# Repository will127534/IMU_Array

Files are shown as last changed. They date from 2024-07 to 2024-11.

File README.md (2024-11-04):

# IMU sensor Array   
Based on 32x ICM-42688-P and ICE40UP5K

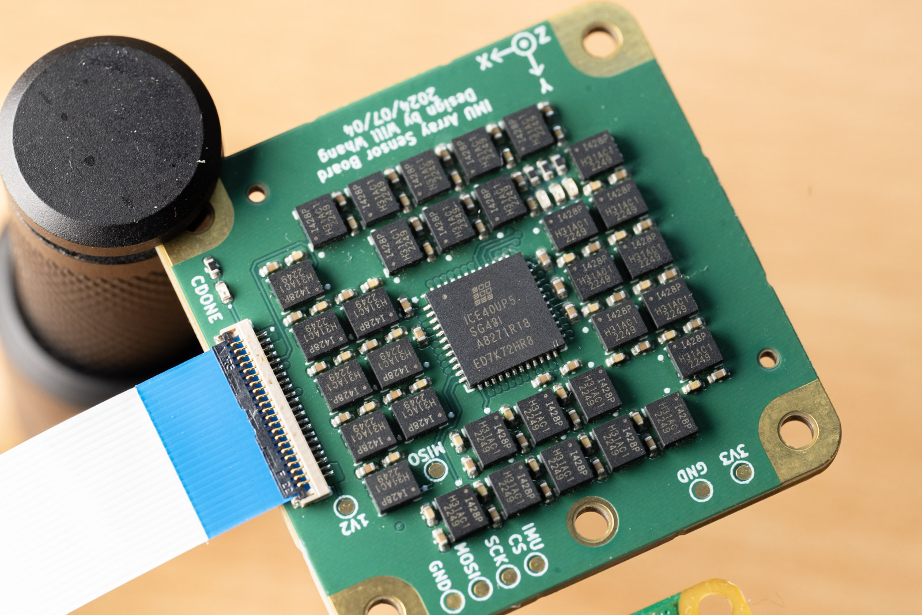
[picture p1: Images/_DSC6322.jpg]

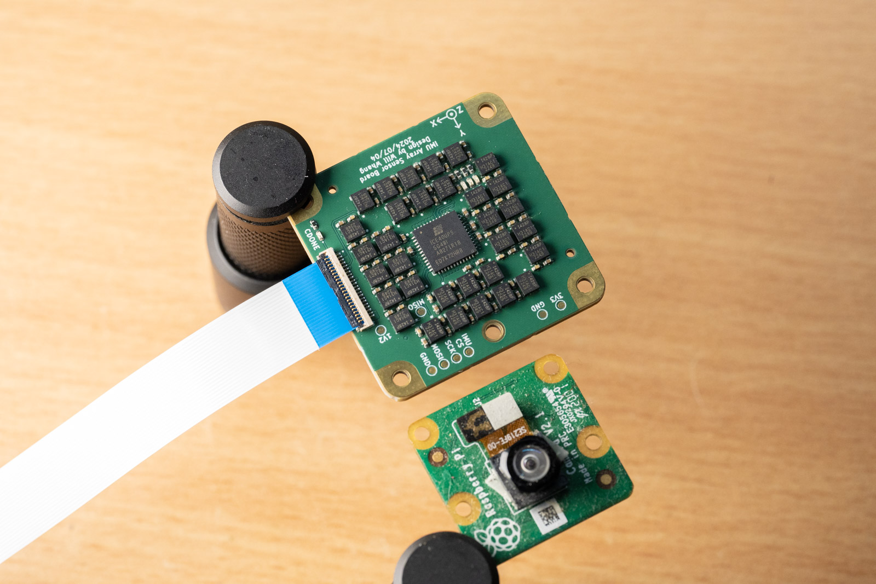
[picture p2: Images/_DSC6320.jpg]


## System Block Diagram
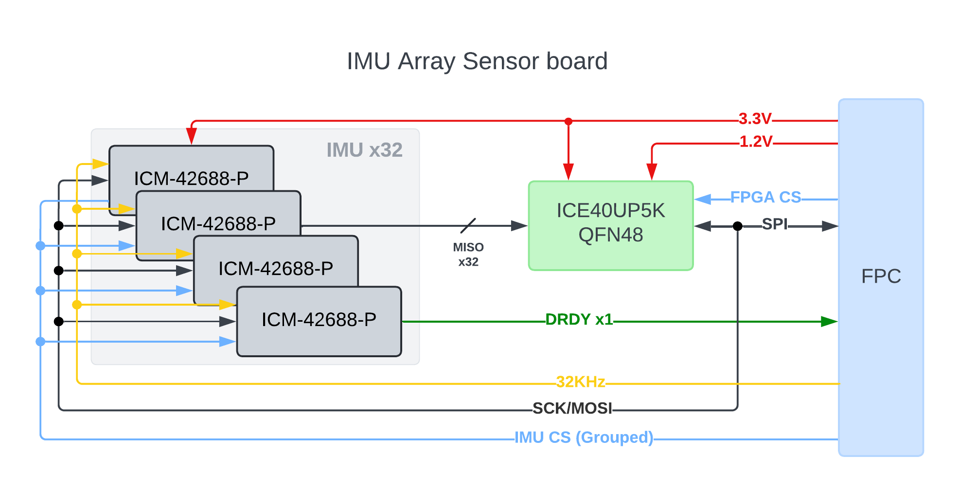
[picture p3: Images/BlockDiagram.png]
BlockDiagram


Blog post: [https://www.willwhang.dev/Project-IMU-Array/](https://www.willwhang.dev/Project-IMU-Array/)

## Dictionary Structure

* IMUArray_SensorBoard: KiCad files for the Sensor board
* IMUArray_BreakoutBoard: KiCad files for the Sensor breakout board with Raspberry Pi Pico  
* MicroPythonCode: MicroPython code for Raspberry Pi Pico  
* FPGACode: Verilog files for the FPGA

## Notes
The hardware is specifically designed for 6-layer board and as you can see from the photos it is using via-in-pad, though I still need to use smaller via dimensions (0.2mm drill). Gerber, BOM and CPL files are also available. Or you can order it from PCBWay [here](https://www.pcbway.com/project/shareproject/IMU_Array_Sensor_board_84cfc54a.html). (Thank you PCBWay for sponsering this project!)

You can have them populate top side only, the back side are some 0402 decoupling caps that can be easily hand soldered. Do note that the FPC connector is selected because it has the least width, but the plastic latch is way fragile then I though, so becareful.   

As for the breakout board, it is really just for supporting the bring up process, I'm gonna design some other based boards to use this IMU array for my other projects (Geophone replacements).  

The code is still in its early stages so there isn't a lot of "Handy" functions to set different ODR (Sampling rate)/FSR (Full Scale range) and functions, but mostly just hand calculated values for the registers. Rightnow it is set to 200Hz sampling rate with interupt and external 32Khz clock enabled. For the Verilog code, please don't judge, I'm too lazy to save 4096 LUTs for the 512 byte IMU data, I mean for some reason ICE40UP5K is pretty cheap so I might as will to utilized it fully, right?  

Most importantly, the code right now does not do any fancy data processing but only reading out 32x IMU data and either send all of them or do a simple average (accumulating only actually) and output the result (it does handle the 4 different rotations of the IMUs).  

The project is still in developments, and here are the issues:  
1. SPI clock is not stable higher then 5Mhz to the FPGA, work is on-going to move the data shifting posedge from ICE40 internal 48Mhz clock to use SCK directly.  
    UPDATE on 2024/08/04 - This has been resolved, now I can run the SPI at 20Mhz.
2. Currently it is not possible to send out all IMU data at 200Hz, but only the averaged value. The bottleneck is in microPython code to print out the data to USB-CDC.  
   UPDATE on 2024/08/04 - Overclocked to 250Mhz so I can send out 100Hz x32 IMUs data to PC, so the focus now is the algorithm to filter out data.

## Footnotes

ICE40 micropython/circuitpython upload code from:   
https://github.com/skerr92/Oakdevtech_CircuitPython_IcePython  
Which is actually designed for the IcyBlue FPGA Feather board (ICE40 + RP2040 on a Feather board)   
https://www.tindie.com/products/oakdevtech/icyblue-fpga-feather-v2/  

[Interactive BOM](https://htmlpreview.github.io/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) [(provided by InteractiveHtmlBom)
](https://github.com/openscopeproject/InteractiveHtmlBom) 

Papers and Inspirations:  
1. The inspirations comes from Sony's crazy 16x IMU array board for SPRESENSE, which is so powerfull that is it export controlled.   

https://monoist.itmedia.co.jp/mn/articles/2404/26/news134.html

2. Kamata, Hiroyuki et al. “MEMS Gyro Array Employing Array Signal Processing for Interference and Outlier Suppression.” 2020 IEEE International Symposium on Inertial Sensors and Systems (INERTIAL) (2020): 1-4. 
https://ieeexplore.ieee.org/document/9090089   
https://www.kenkai.jaxa.jp/research/innovation/multi_imu.html  
https://www.sony.com/ja/SonyInfo/technology/stories/entries/Spresense/  
This is also what Sony's IMU array board is based of I think.

3. Blocher, Lukas et al. “Purely Inertial Navigation with a Low-Cost MEMS Sensor Array.” 2021 IEEE International Symposium on Inertial Sensors and Systems (INERTIAL) (2021): 1-4.
https://ieeexplore.ieee.org/document/9430468

5. Wang, Liqiang et al. “Improving the Navigation Performance of the MEMS IMU Array by Precise Calibration.” IEEE Sensors Journal 21 (2021): 26050-26058.
http://i2nav.com/ueditor/jsp/upload/file/20221125/1669361019644065348.pdf

6. Nilsson, John-Olof et al. “Aligning the Forces—Eliminating the Misalignments in IMU Arrays.” IEEE Transactions on Instrumentation and Measurement 63 (2014): 2498-2500.
https://ieeexplore.ieee.org/document/6879287

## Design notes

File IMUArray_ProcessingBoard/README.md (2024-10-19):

# IMU Array Data Processing Board

Here is the board and code for the processing board I'm designing mainly for my geophone replacement project.
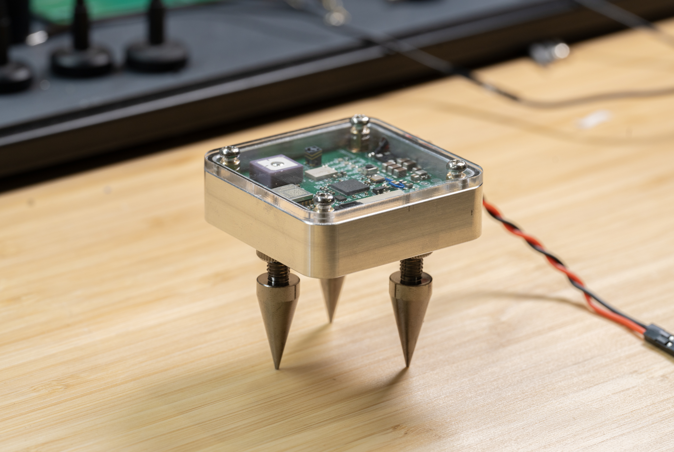
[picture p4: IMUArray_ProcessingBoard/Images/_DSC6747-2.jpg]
Board photo


## System Block Diagram
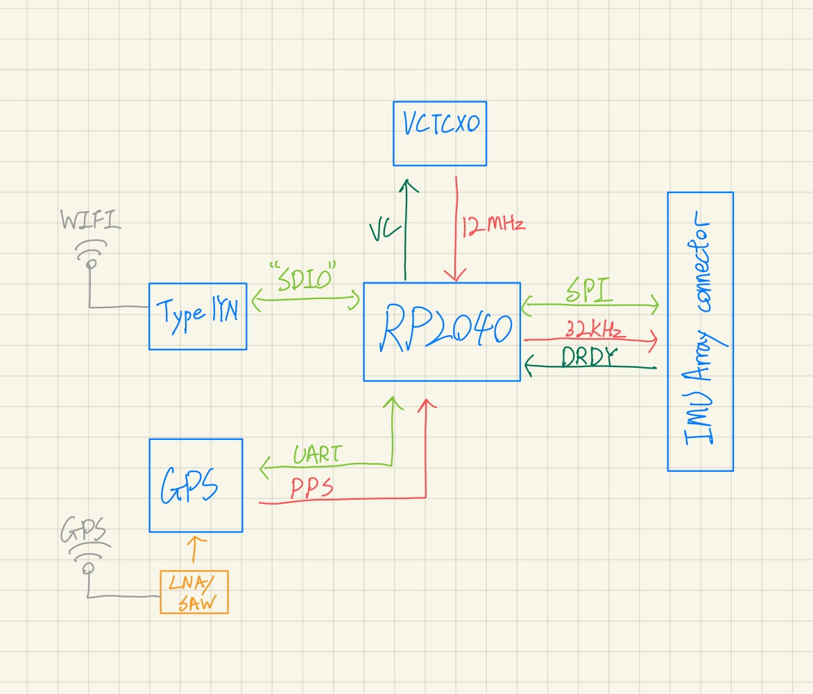
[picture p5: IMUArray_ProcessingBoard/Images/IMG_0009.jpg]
System Block Diagram


## Dictionary Structure

* IMUArray_ProcessingBoard: KiCad files for the board
* Code: C Code for the board

## Hardware Notes

So, long story short, this is essentially a custom-built Pico W using the same RP2040 + CYW43439 (Type 1YN) combo. Additionally, the crystal for the RP2040 was replaced with a VCTCXO, allowing me to tune the onboard clock to match the GPS clock (i.e., GPSDO). The code supports both NTP and GPS+PPS as time sync sources. The main reason for this is that I’m using the same crystal to send a stable 32kHz signal to the IMU array.

You might ask, why on earth do I have a full bridge rectifier along with a high-voltage DC-DC step-down converter? This was mainly because I initially intended to use my doorbell system (24V AC) to power the system. I kind of regret this decision, so it was removed in v2.0 (I’m waiting for the board to arrive).

Furthermore, I originally planned to rely on Wi-Fi to transmit the data, so the USB connector (JST-SH) wasn’t designed for external connection but only for programming. See more on the blog post. However, I ended up deciding to make the USB accessible from the case in the future v2.0 design.

## Software Notes

In the code folder, you’ll find two files. The goal for `imu_simple` is to have a much simpler codebase, so two years later, I can still understand what’s going on or easily test new ideas. `imu_main` is the main code I’m currently using, which follows the structure outlined below:

The data can be sent via either TCP or USB. If a client connects to the TCP server, it will switch to sending data through TCP. During startup, and once per hour, the system performs an NTP time sync. If GPS is available, it also uses it to calculate the UNIX timestamp offset from the internal system clock. As a result, each IMU sample contains not only the timestamp from the IMU itself but also a UNIX timestamp. However, note that these two timestamps are not strongly related (since the GPSDO requires time to adjust the error).

For IMU data processing, the code uses the method described in Reference 6 to calibrate the IMU array. Refer to the MATLAB code section for generating imu_cal.h. The data processing applies the calibration and merges the 32 IMU data into one dataset. The RP2040 is surprisingly fast enough to handle all of this using floating-point operations, even without hardware FPU, and can run at up to 500Hz. A side note here is that to measure the processing time, I placed the data processing code along with the SPI read function. By measuring the CS pin, I can determine the total time spent on both data acquisition and processing. The 500Hz rate accounts for both tasks in sequence, not in parallel (i.e., I’m not using both CPU cores for reading and processing, but instead for reading/processing and Wi-Fi/Bluetooth data processing).

Lastly, I’m not entirely sure how to share the code I wrote under the RP2040 SDK’s pico-example folder, so you may need to figure out how to set up the build environment outside of the SDK. Also, please let me know how to share it if you have suggestions.

## Footnotes

[Interactive BOM](https://htmlpreview.github.io/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) [(provided by InteractiveHtmlBom)
](https://github.com/openscopeproject/InteractiveHtmlBom) 

PIO input capture code from: https://people.ece.cornell.edu/land/courses/ece4760/RP2040/C_SDK_PIO_control/Input_capture/index_pio_control.html

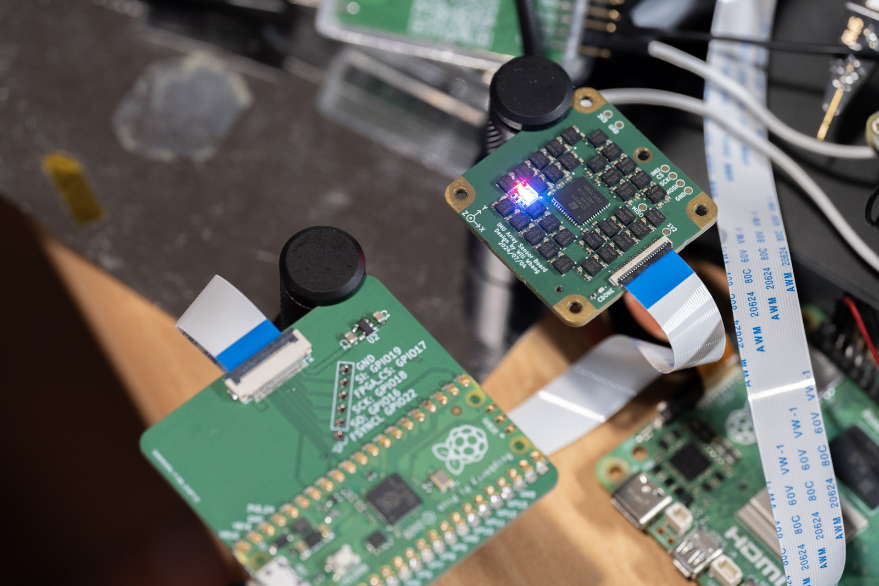
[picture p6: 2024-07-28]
Images/_DSC6333.jpg

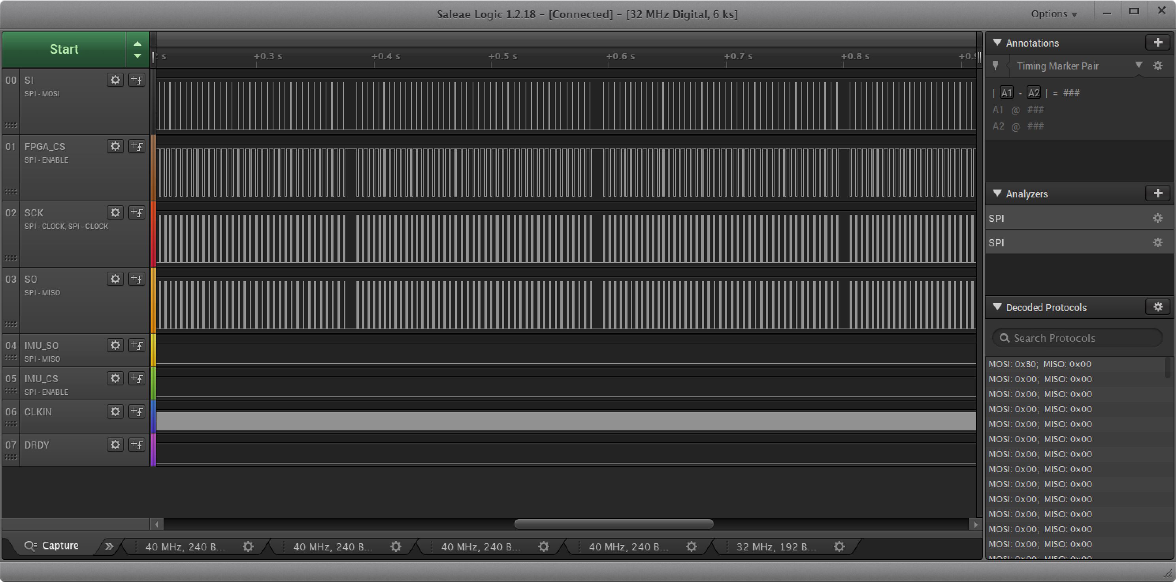
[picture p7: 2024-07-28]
Images/WaveForm1.jpg

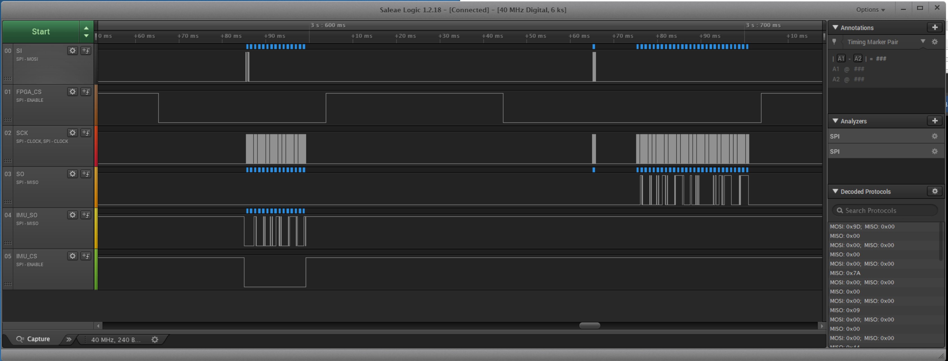
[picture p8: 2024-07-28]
Images/WaveForm2.jpg

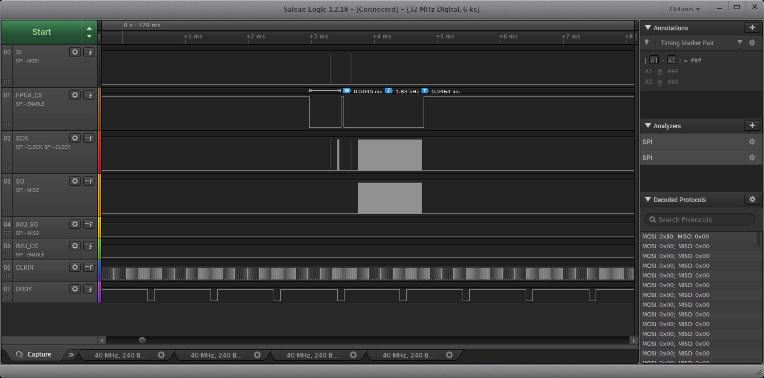
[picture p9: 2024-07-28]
Images/WaveForm3.jpg

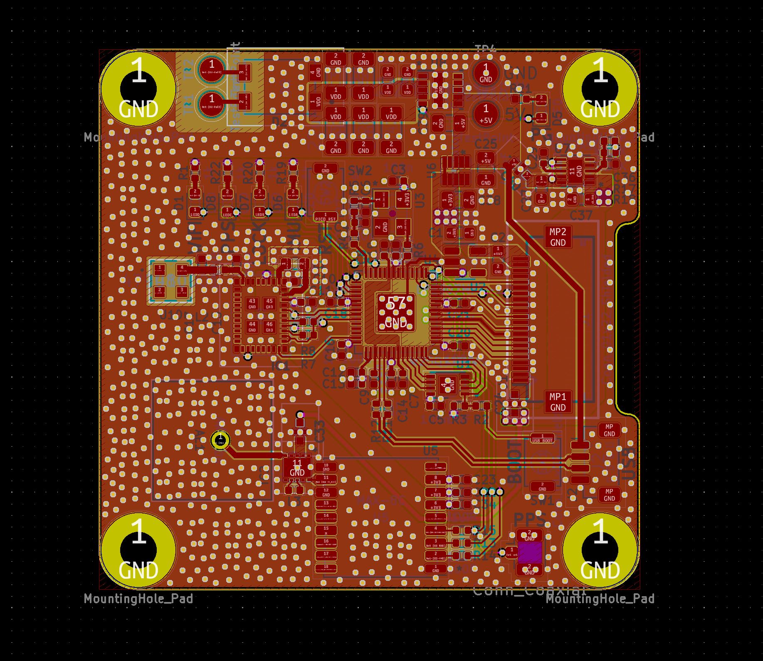
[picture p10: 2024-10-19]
IMUArray_ProcessingBoard/IMUArray_ProcessingBoard/board.jpg

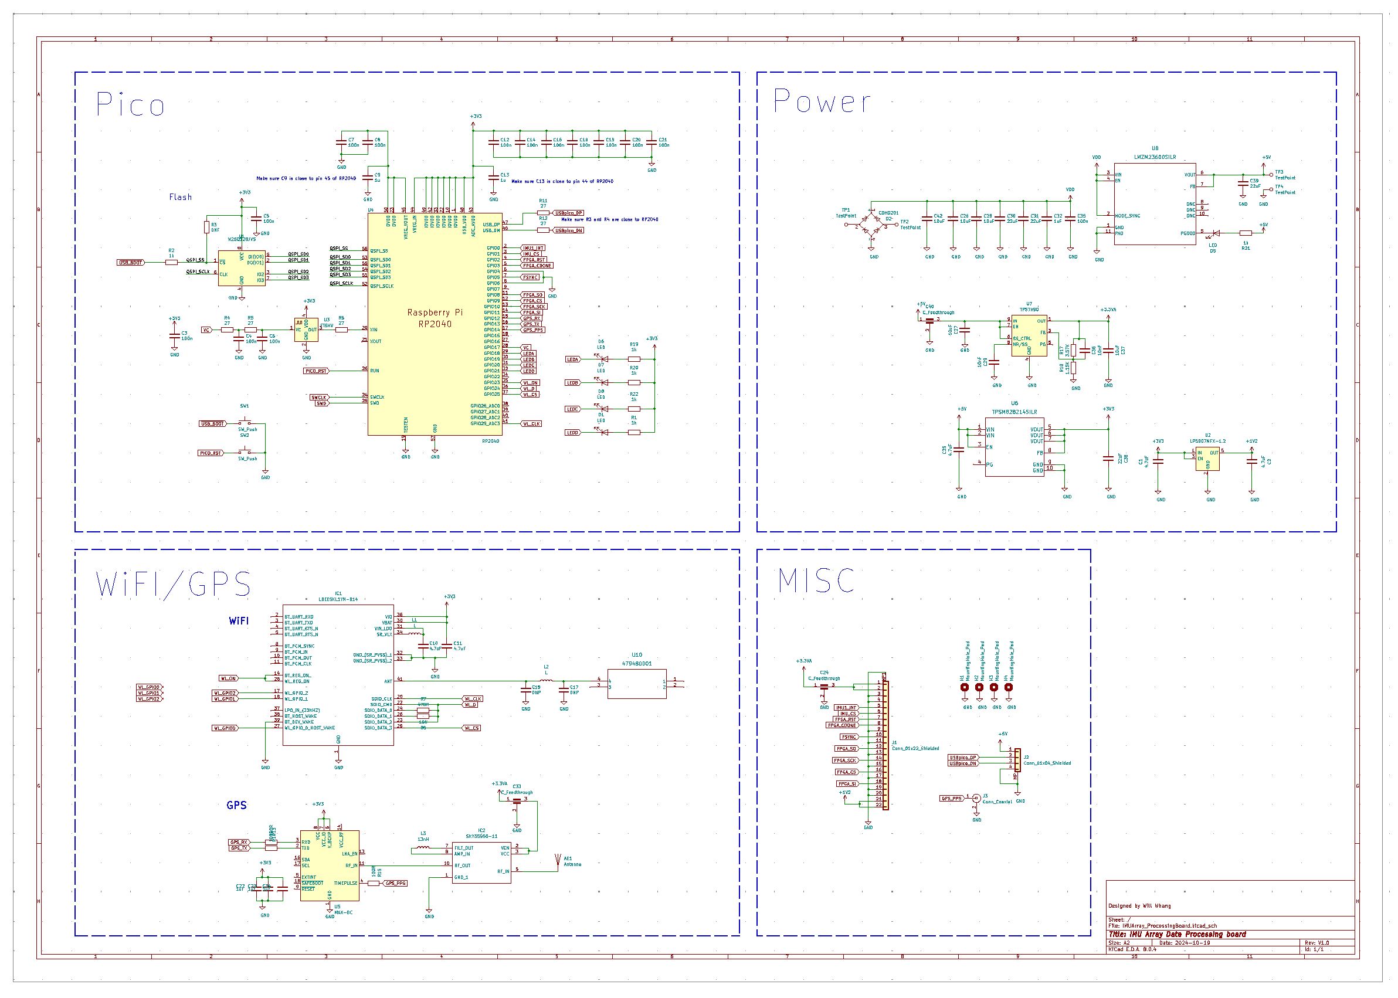
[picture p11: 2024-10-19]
IMUArray_ProcessingBoard/IMUArray_ProcessingBoard/sch.jpg

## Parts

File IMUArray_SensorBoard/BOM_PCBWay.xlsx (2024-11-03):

 |  |  | IMU array Sensor 1PCS BOM (Sample Bill of Materials)
Item # | *Designator | *Qty | Manufacturer | *Mfg Part # | Description / Value | *Package/Footprint | Type | Your Instructions / Notes
1 | C1, C2, C4, C5, C6, C7, C8, C9, C10, C11, C12, C13, C14, C15, C32, C33, C34, C35, C36, C37, C38, C39, C56, C57, C58, C59, C60, C61, C62, C63, C80, C81, C82, C83, C84, C85, C86, C87, C111 | 39 |  |  | CAP CER 100nF 16V X7R 0402 | 0402 | SMD
2 | C16, C17, C18, C19, C20, C21, C22, C23, C40, C41, C42, C43, C44, C45, C46, C47, C64, C65, C66, C67, C68, C69, C70, C71, C88, C89, C90, C91, C92, C93, C94, C95 | 32 |  |  | CAP CER 10nF 16V X7R 0402 | 0402 | SMD
3 | R3, R4, R5, R6 | 4 |  |  | RES 330R OHM 1/8W 1% 0402 SMD | 0402 | SMD
4 | D1, D3 | 2 |  |  | GREEN LED 0402 | 0402 | SMD
5 | D2 | 1 |  |  | RED LED 0402 | 0402 | SMD
6 | D4 | 1 |  |  | BLUE LED 0402 | 0402 | SMD
7 | U1, U2, U3, U4, U5, U6, U7, U8, U9, U10, U11, U12, U13, U14, U15, U16, U17, U18, U19, U20, U21, U22, U23, U24, U25, U26, U27, U28, U29, U30, U31, U32 | 32 | TDK InvenSense | ICM-42688-P | ICM42688-P IMU | PQFN50P300X250X97-14N | SMD
8 | U33 | 1 | Lattice | ICE5LP1K-SG48 | ICE5LP1K-SG48 | QFN-48 | SMD
9 | J1 | 1 | Hirose | FH19SC22S05SH09 | FH19SC22S05SH09 | Conn_01x22_Shielded | SMD
Need a quick and accurante quote? Need an efficient production? Please read SMT Ordering Necessary Files & Info in 1 minute. Thank you very much! (https://www.pcbway.com/smt_ordering_guide.html)
Click for Instructions on How to Create a BOM (https://www.pcbway.com/blog/PCB_Assembly/How_to_Build_a_BOM__Bill_Of_Materials_.html)

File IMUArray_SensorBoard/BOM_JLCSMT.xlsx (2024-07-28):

Comment | Designator | Footprint | JLCPCB Part #（optional）
330R | R3,R6,R5,R4 | R_0402_1005Metric | C245037
10nF | C21,C67,C40,C69,C44,C94,C65,C47,C19,C64,C18,C66,C92,C88,C91,C95,C17,C42,C16,C93,C20,C71,C68,C43,C70,C23,C45,C46,C90,C89,C22,C41 | C_0402_1005Metric | C338031
100n | C87,C86,C85,C63,C62,C61,C39,C38,C15,C14,C13,C12,C11,C35,C37,C36,C84,C34,C8,C80,C33,C60,C58,C6,C59,C57,C32,C56,C82,C4,C81,C83,C5,C1,C2,C7,C111,C9,C10 | C_0402_1005Metric | C3901090
2.2uF | C79,C78,C77,C55,C54,C53,C52,C51,C31,C30,C29,C28,C27,C103,C102,C101,C75,C26,C97,C96,C72,C48,C50,C100,C49,C99,C24,C76,C73,C98,C25,C74 | C_0402_1005Metric
GREEN | D1,D3 | LED_0402_1005Metric | C434449
4.7uF | C3,C113,C112 | C_0402_1005Metric
ICE5LP1K-SG48 | U33 | QFN-48-1EP_7x7mm_P0.5mm_EP5.6x5.6mm | C2678152
ICM-42688-P | U15,U31,U32,U22,U28,U26,U1,U11,U8,U25,U16,U4,U5,U30,U13,U14,U12,U21,U9,U7,U10,U27,U6,U3,U19,U18,U29,U24,U20,U17,U23,U2 | PQFN50P300X250X97-14N | C1850418
BLUE | D4 | LED_0402_1005Metric | C434447
RED | D2 | LED_0402_1005Metric | C434445
Conn_01x22_Shielded | J1 | FH19SC22S05SH09 | C3168185

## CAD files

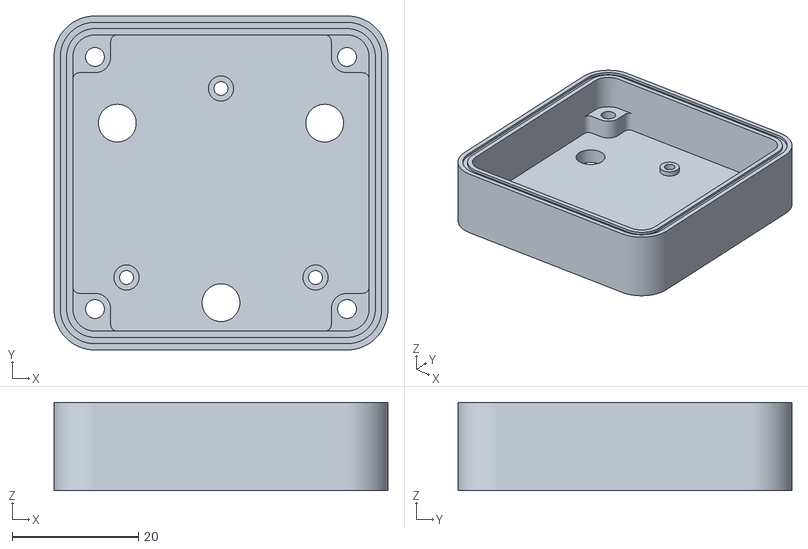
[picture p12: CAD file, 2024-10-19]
IMUArray_ProcessingBoard/3D_STL/Body.stl
53.0 x 53.0 x 14.0

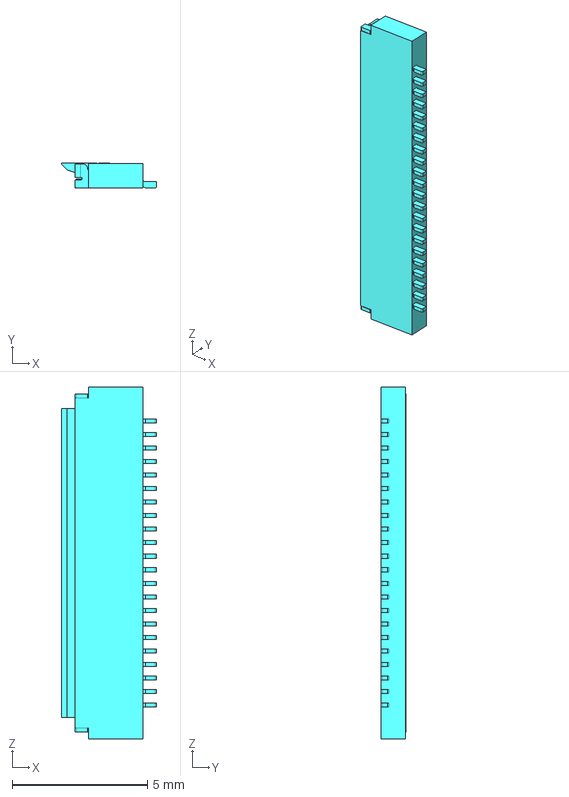
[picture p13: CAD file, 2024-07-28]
IMUArray_SensorBoard/3D/FH19SC-22S-0.5SH(09).STEP
3.50 x 0.93 x 13.0 mm

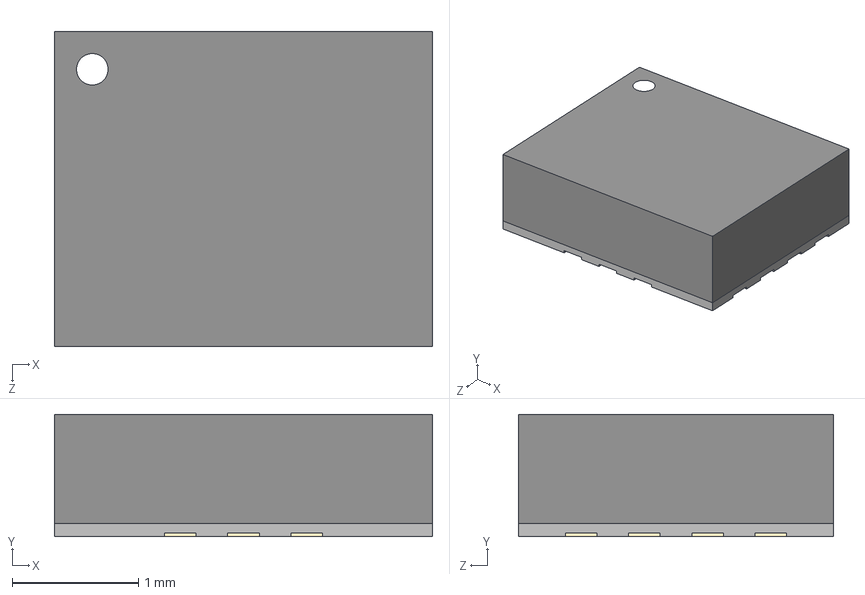
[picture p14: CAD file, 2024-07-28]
IMUArray_SensorBoard/3D/ICM-42688-P.step
3.00 x 0.97 x 2.50 mm

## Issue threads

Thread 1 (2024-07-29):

Is there a dataset demo?

qpc001, 2024-07-29:

will127534, 2024-07-29:
Two separate runs:
[20240728190930.csv](https://github.com/user-attachments/files/16406410/20240728190930.csv)
[20240728190439.csv](https://github.com/user-attachments/files/16406411/20240728190439.csv)

The averaged one is at 200Hz, full data in 50Hz

will127534, 2024-07-29:
full data in 50Hz - I forgot to print it as float. the data is in mg and dps for this.
[20240728191400.csv](https://github.com/user-attachments/files/16406472/20240728191400.csv)

The averaged one is accumulated all the IMUs data in raw ADC.

will127534, 2024-08-02:
Here are the dataset and the code I used to record + analyze.
https://github.com/will127534/IMU_Array/tree/analyzer

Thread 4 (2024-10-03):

Avoiding FPGA - possible simplification

aaronjauf, 2024-10-03:
Hello,
very nice project and thank you for sharing!
Did you already try indoor navigation using the IMU array and are do you expect 100 Hz to be enough for a e.g. vacuum cleaner rover?
I was wondering if the FPGA can be eliminated: My idea is to use a raspberry pi pico and interfacing the I2C interfaces of the IMUs using the PIO/DMA. The clock line can be shared, allowing for 27 IMUs (since the pico has 28 gpio lines), if all IMUs are set to the same I2C address, otherwise 54 IMUs. What's your opinion on this?

Best regards
Aaron

will127534, 2024-10-04:
So originally I did think about using RP2040 but because of the lack of GPIO (I want to do 32 IMU) and some bad timing (RP2350 released a couple weeks after I got the board back), I end up going with a FPGA, but it is not that expensive though.

Issue with I2C is speed and complexity compare to SPI bus, you are limited to 1Mhz while SPI in this project is running at 20Mhz.

Overall if I have a second revision in the future I'll go with RP2350 + SPI to the IMUs, I think that is the ultimate solution.

nippoo, 2024-10-15:
Hey, thanks for the great project! I'm interested in porting this to an MCU - do you have any other thoughts? (I'd happily send over a PR, though likely makes sense to keep two separate projects as it's a bit of a redesign...) I'd like to run some slightly more advanced algorithms: interference suppression (to remove resonances from closely mounted IMUs), an outlier filter (to discard any out-of-tolerance IMUs), and a Kalman filter for position estimation (as well as something to calculate and cancel out the earth's precession!). So I'm considering either the RP2350, or something a little bit more powerful where the SPI I/O can run on one core and the more sophisticated algorithms can run on a fixed 100Hz loop on the other core...

As an aside: why did you choose the ICM-42688-P? It has the same stated random walk (2.8mdps/sqrt(Hz)) as the ST LSM6DSV IMU, which is half the price, so I'm curious if you've tested/know it to be better or if there's any other reason!

aaronjauf, 2024-10-16:
I believe the reference work uses the ICM ( https://www.youtube.com/watch?v=7fgcxDRti5s ). As for the MCU, I believe the RP2040 would be sufficient (since the RP2350 is not yet available). One GPIO for MOSI, one for SCK, two for CS (16 IMUs + 16 IMUs), 16 for MISO. So the idea is to read out 16 IMUs in parallel, then the next 16. This can be done using PIO and DMA.

will127534, 2024-10-16:
The reason at least for me to use these ICM IMUs is because they have a very unique feature - You can send a 30~40Khz clock through the pins and clock its internal ASIC, which guarantees synchronization among all the sensor and MCU and you don't have to deal with traditional FSYNC (Or any external sync signal) that only gives you the time delta between last measurements and your external event and you will need to do linear interpolation.

Sidenote here: So after this project bring-up phase and having more familiar with this IMU I've added it to my camera boards and uses FSYNC function with Vsync output from the camera sensors, so now I do have both experience (CLKIN vs FSYNC). I'm so glad that I've got this IMU and uses the CLKIN in this IMU array project, otherwise it is going to be a pain to do synchronization.

As for the algorithm, I haven't finish writing the report yet but I'm able to replicate reference 6 (Aligning the Forces—Eliminating the Misalignments in IMU Arrays - by John-Olof Nilsson et. al) to calibrate the IMU array and run the calibration with RP2040 @ 240Mhz with 500Hz IMU data output. Yes I did use both CPU cores with one deliciated to IMU + calibration/array fusion processing and the other for WiFi/GPS ... etc, but I'm still surprised with the performance I can get with RP2040. (The calibration is even running in floating point lol).

will127534, 2024-10-16:
The thing that you need to keep in mind is synchronization: Not just IMU array itself but with other systems too.
So the pin count may be good enough on paper but having a few more to do clock adjustment will be much better. At least this is what I think right now.

Feel free to just grab the files here and starts your own repo though, git isn't good for HW design anyways lol. Also, if you have any good papers on the filtering stuff please do post some links here : )

will127534, 2024-10-16:
Sony is using ST also, see reference 2 for details. (H. Kamata, M. Kimishima, T. Sawada, Y. Suga, H. Takeda, K. Yamashita, and S. Mitani, MEMS Gyro Array Employing Array Signal Processing for Interference and Outlier Suppression, IEEE Inertial 2020, Hiroshima, Japan)

DSIsaac, 2024-10-17:
Hello，
I had tried IMU array with 2 imu, but it
 don't solve the problem of IMU YAW axis drift. So how did you solve this problem？Can I solve this problem by increase the quantity of IMU?

NightHawk32, 2024-10-18:
> Hello， I had tried IMU array with 2 imu, but it don't solve the problem of IMU YAW axis drift. So how did you solve this problem？Can I solve this problem by increase the quantity of IMU?

Hey, author of
Purely Inertial Navigation with a Low-Cost MEMS Sensor Array by Lukas Blocher et. al
https://ieeexplore.ieee.org/document/9430468
here. To deal with the yaw drift is not an easy task. You will gain a decrease of noise of sqrt(n) with n IMUs. But since you lack the reference it is hard to deal with the drifting offsets. On x and y you can use gravity as a reference, for the Z-axis this would require an additional sensor. But when choosing a high quality sensor you can keep up the yaw angle over 10min or longer and still stay within a 1deg range of precision.
What are your requirements exactly?

In my experience calibrating offsets, sensitivity and misalignment of all IMUs within the array is crucial.

nippoo, 2024-10-26:
Hi @will127534, thanks for your reply - seems like there are about 3 threads going on in parallel right now. 😅

All the papers I've read have already been linked in this thread. The production version uses a CY8C6247BZI MCU, it seems (with 8 I2C/SPI peripherals). The linked video has some interesting insights - at 20:06 they imply the IMUs aren't synchronised and the FPGA is presumably handling synchronisation. I assume there's a good reason they've done this, but perhaps it's just a tradeoff of a bit of development time vs being able to double the number of IMUs at the same cost.

On another ST thread someone suggested you could start the IMU measurement by simultaneously toggling the CS pin low. I wonder if this would work, and why they've chosen that MCU - with 16 sensors you could read them in 2 sets of 8, sequentially: https://community.st.com/t5/mems-sensors/how-to-configure-and-synchronize-lsm6dso-to-raspeberry-pi/m-p/189524

That said, linear interpolation isn't massively complex either. I need to do a bit of digging to figure out how easy it is to get reliable timestamps from the data...

nippoo, 2024-10-26:
@gmaxwell to your issue, even if your gyro is in a fixed location/orientation, the problem is still intractable: yaw drift in the plane perpendicular to gravity is impossible to calculate unless you have an external reference.

This does bring up a more interesting issue generally though: how reliable/consistent is the drift on each gyro? Is it random noise or could you calibrate / bin the IMUs to find the best one?

Looking at the graph from the paper linked above, it looks like some individual IMUs perform better than the calculated average of all 16 (there are a couple of purple lines below the blue average trace at the bottom right of the graph). Rather than going to all the effort of combining sensors etc, could you just instead leave them all on for a day, and select the best one, and discard all other results?

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

will127534, 2024-10-26:
@nippoo I'm pretty much free in terms of where discussion be for my git reops/projects, typically it will be better to start a discussion but most people just asking questions in the issue anyways. Either way works for me, it is not as crazy long as some other issue I've seen on Github.

For the synchronisation I was reading ST's datasheet but I'm very much confused about how the heck do people use it without synchronisation signals, I did not see even the FSYNC functions exists in those IMUs. If I must guess maybe they are using the Data Ready (DRDY) and timestamp it in the FPGA against reference clock, and align all the IMUs with linear interpolation?

I'm not saying that I'm against linear interpolation, it just that if there is a easier way to synchronisation why bother. I think most people looking at this repo probably overestimate the work this project has done, the FPGA code here is merely a data aggregator, while the synchronisation is handled by a relatively niche function in the ICM-42688P that not a lot of people is aware of.

Start the IMU measurement by simultaneously toggling the CS pin won't work because their internal clock is still not aligned among the IMUs, and IMU sampling is based on its internal clock. You might able to start measurements at the same time but as time goes on it will still drift because IMUs can't align/adjust its internal clock just using the CS pin.

Finally, IMU sampling is not a one-shot procedure like how some ADC could be, because the sample have to pass through digital filter which needs a few samples to get started.

will127534, 2024-10-26:
By the way I have some analyzer code in the analyzer branch with the data I've collected, I've also added some code/HW on the data processer board.

will127534, 2024-11-04:
[https://www.willwhang.dev/Project-IMU-Array/](https://www.willwhang.dev/Project-IMU-Array/)

dishilov, 2024-12-21:
@will127534 Thank you for the dev blog writeup.

arifbalik, 2024-12-22:
@nippoo any updates on the mcu port? I could also contribute

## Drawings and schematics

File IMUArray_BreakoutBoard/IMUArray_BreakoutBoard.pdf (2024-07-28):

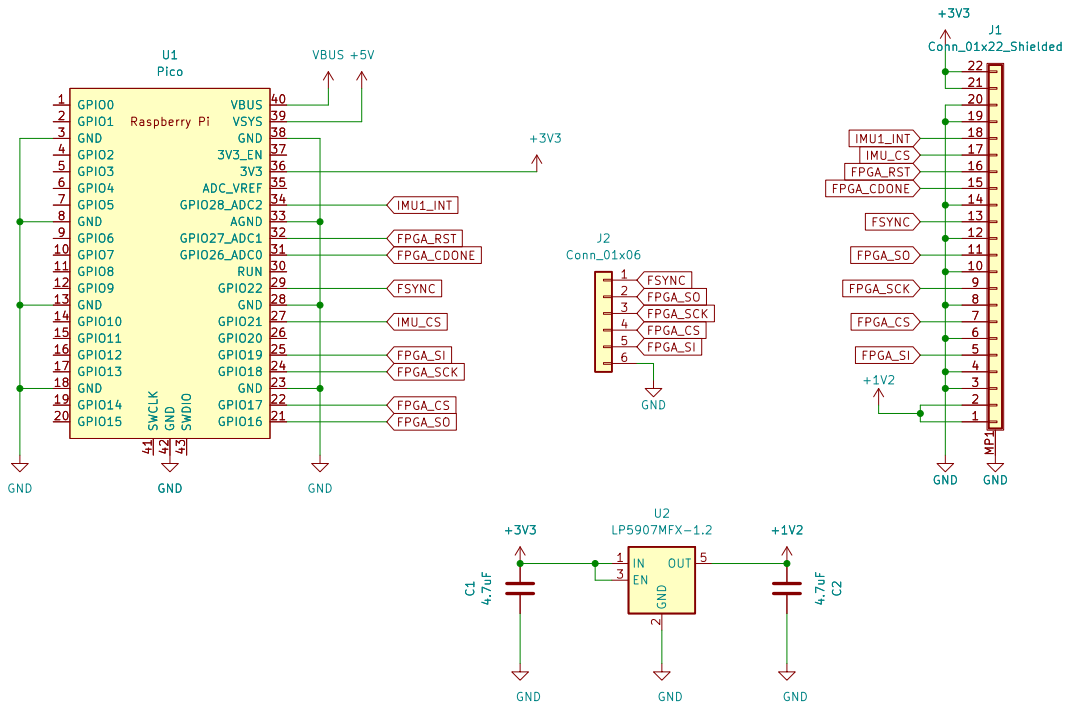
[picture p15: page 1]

File: AccArray_PICO.kicad_sch Sheet: / Designed by Will Whang

Id: 1/1 Title: Breakout board for IMU Array

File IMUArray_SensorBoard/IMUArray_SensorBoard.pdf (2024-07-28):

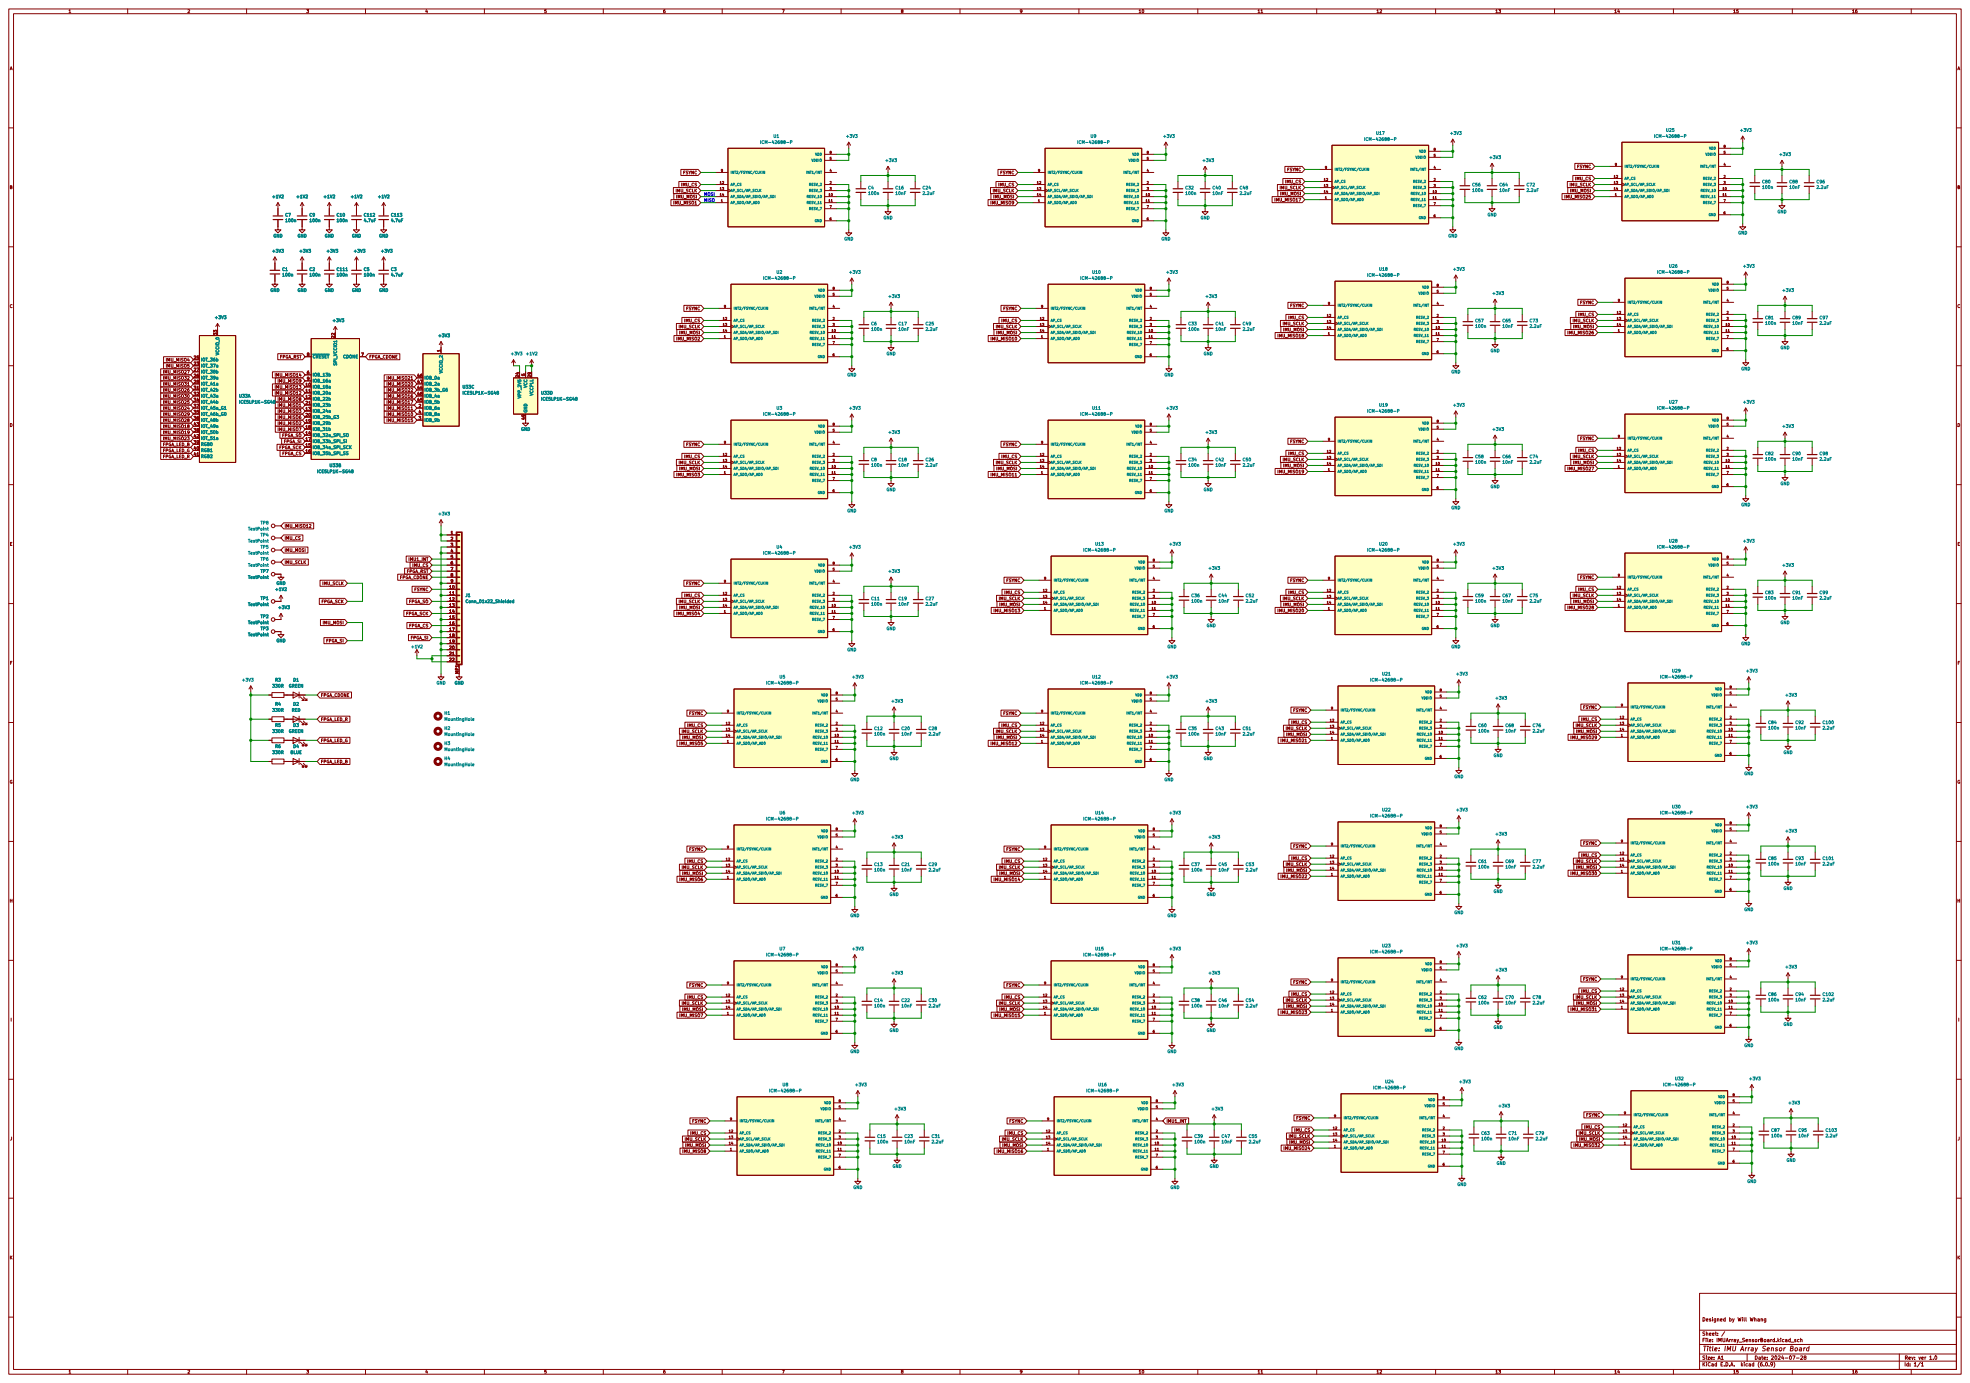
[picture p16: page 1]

File: IMUArray_SensorBoard.kicad_sch Sheet: / Designed by Will Whang

Id: 1/1 Title: IMU Array Sensor Board

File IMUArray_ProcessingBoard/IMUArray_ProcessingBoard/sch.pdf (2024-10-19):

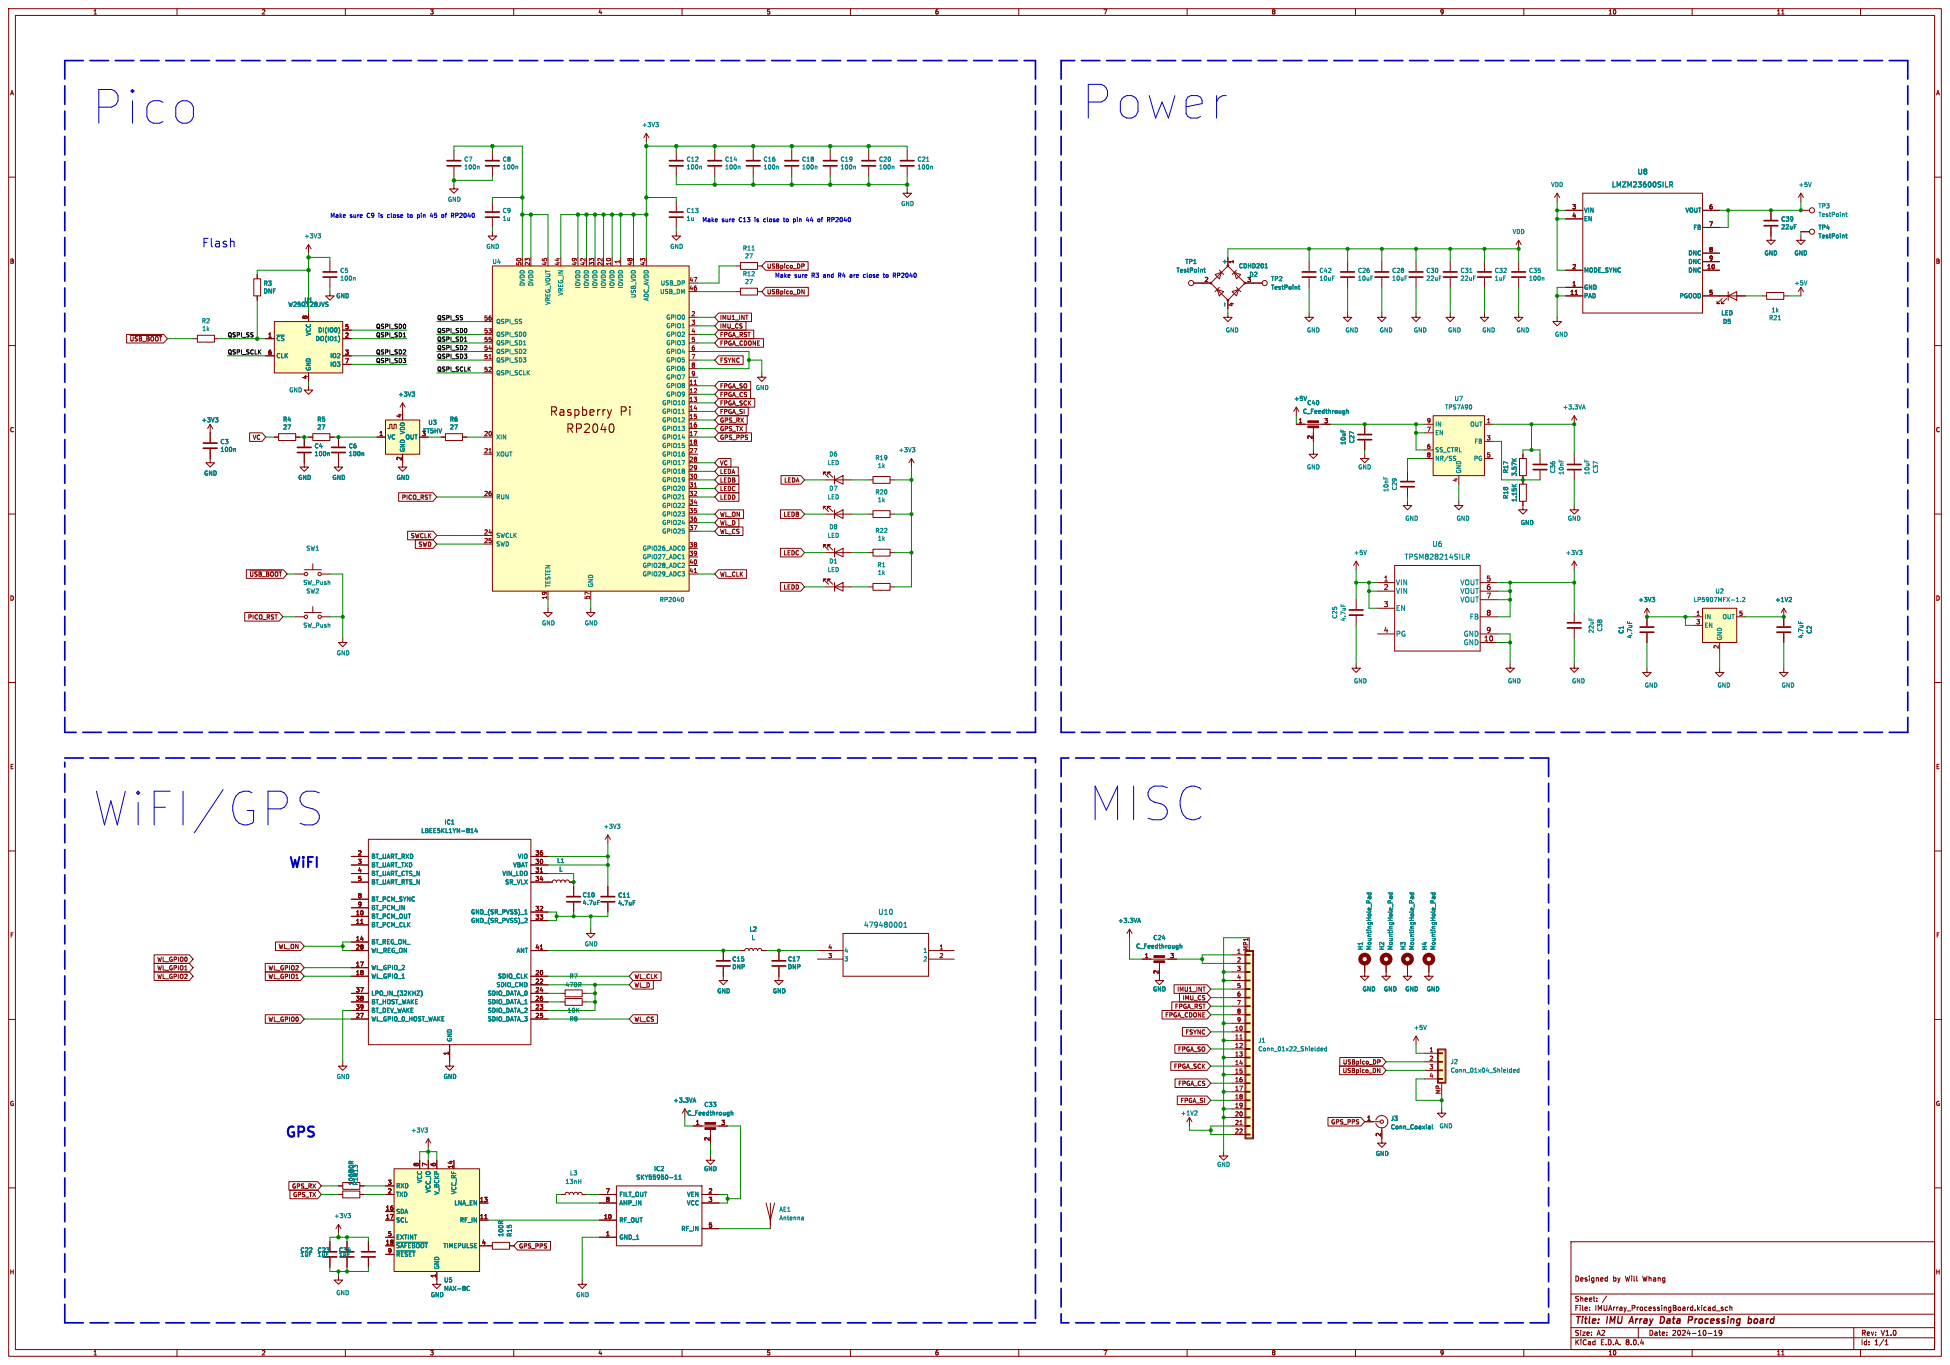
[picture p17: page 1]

Make sure R3 and R4 are close to RP2040 Pico
Make sure C9 is close to pin 45 of RP2040 GPS

Make sure C13 is close to pin 44 of RP2040 Flash

1 IOVDD 10 GPIO8 11 GPIO9 12 GPIO10 13 GPIO11 14 GPIO12 15 GPIO13 16 GPIO14 17 GPIO15 18 TESTEN 19 GPIO0 2 XIN 20 XOUT 21 IOVDD 22 DVDD 23 SWCLK 24 SWD 25 RUN 26 GPIO16 27 GPIO17 28 GPIO18 29 GPIO1 3 GPIO19 30 GPIO20 31 GPIO21 32 IOVDD 33 GPIO22 34 GPIO23 35 GPIO24 36 GPIO25 37 GPIO26_ADC0 38 GPIO27_ADC1 39 GPIO2 4 GPIO28_ADC2 40 GPIO29_ADC3 41 IOVDD 42 ADC_AVDD 43 VREG_IN 44 VREG_VOUT 45 USB_DM 46 USB_DP 47 USB_VDD 48 IOVDD 49 GPIO3 5 DVDD 50 QSPI_SD3 51 QSPI_SCLK 52 QSPI_SD0 53 QSPI_SD2 54 QSPI_SD1 55 QSPI_SS 56 GND 57 GPIO4 6 GPIO5 7 GPIO6 8 GPIO7 9 U4 RP2040 GND GND GND

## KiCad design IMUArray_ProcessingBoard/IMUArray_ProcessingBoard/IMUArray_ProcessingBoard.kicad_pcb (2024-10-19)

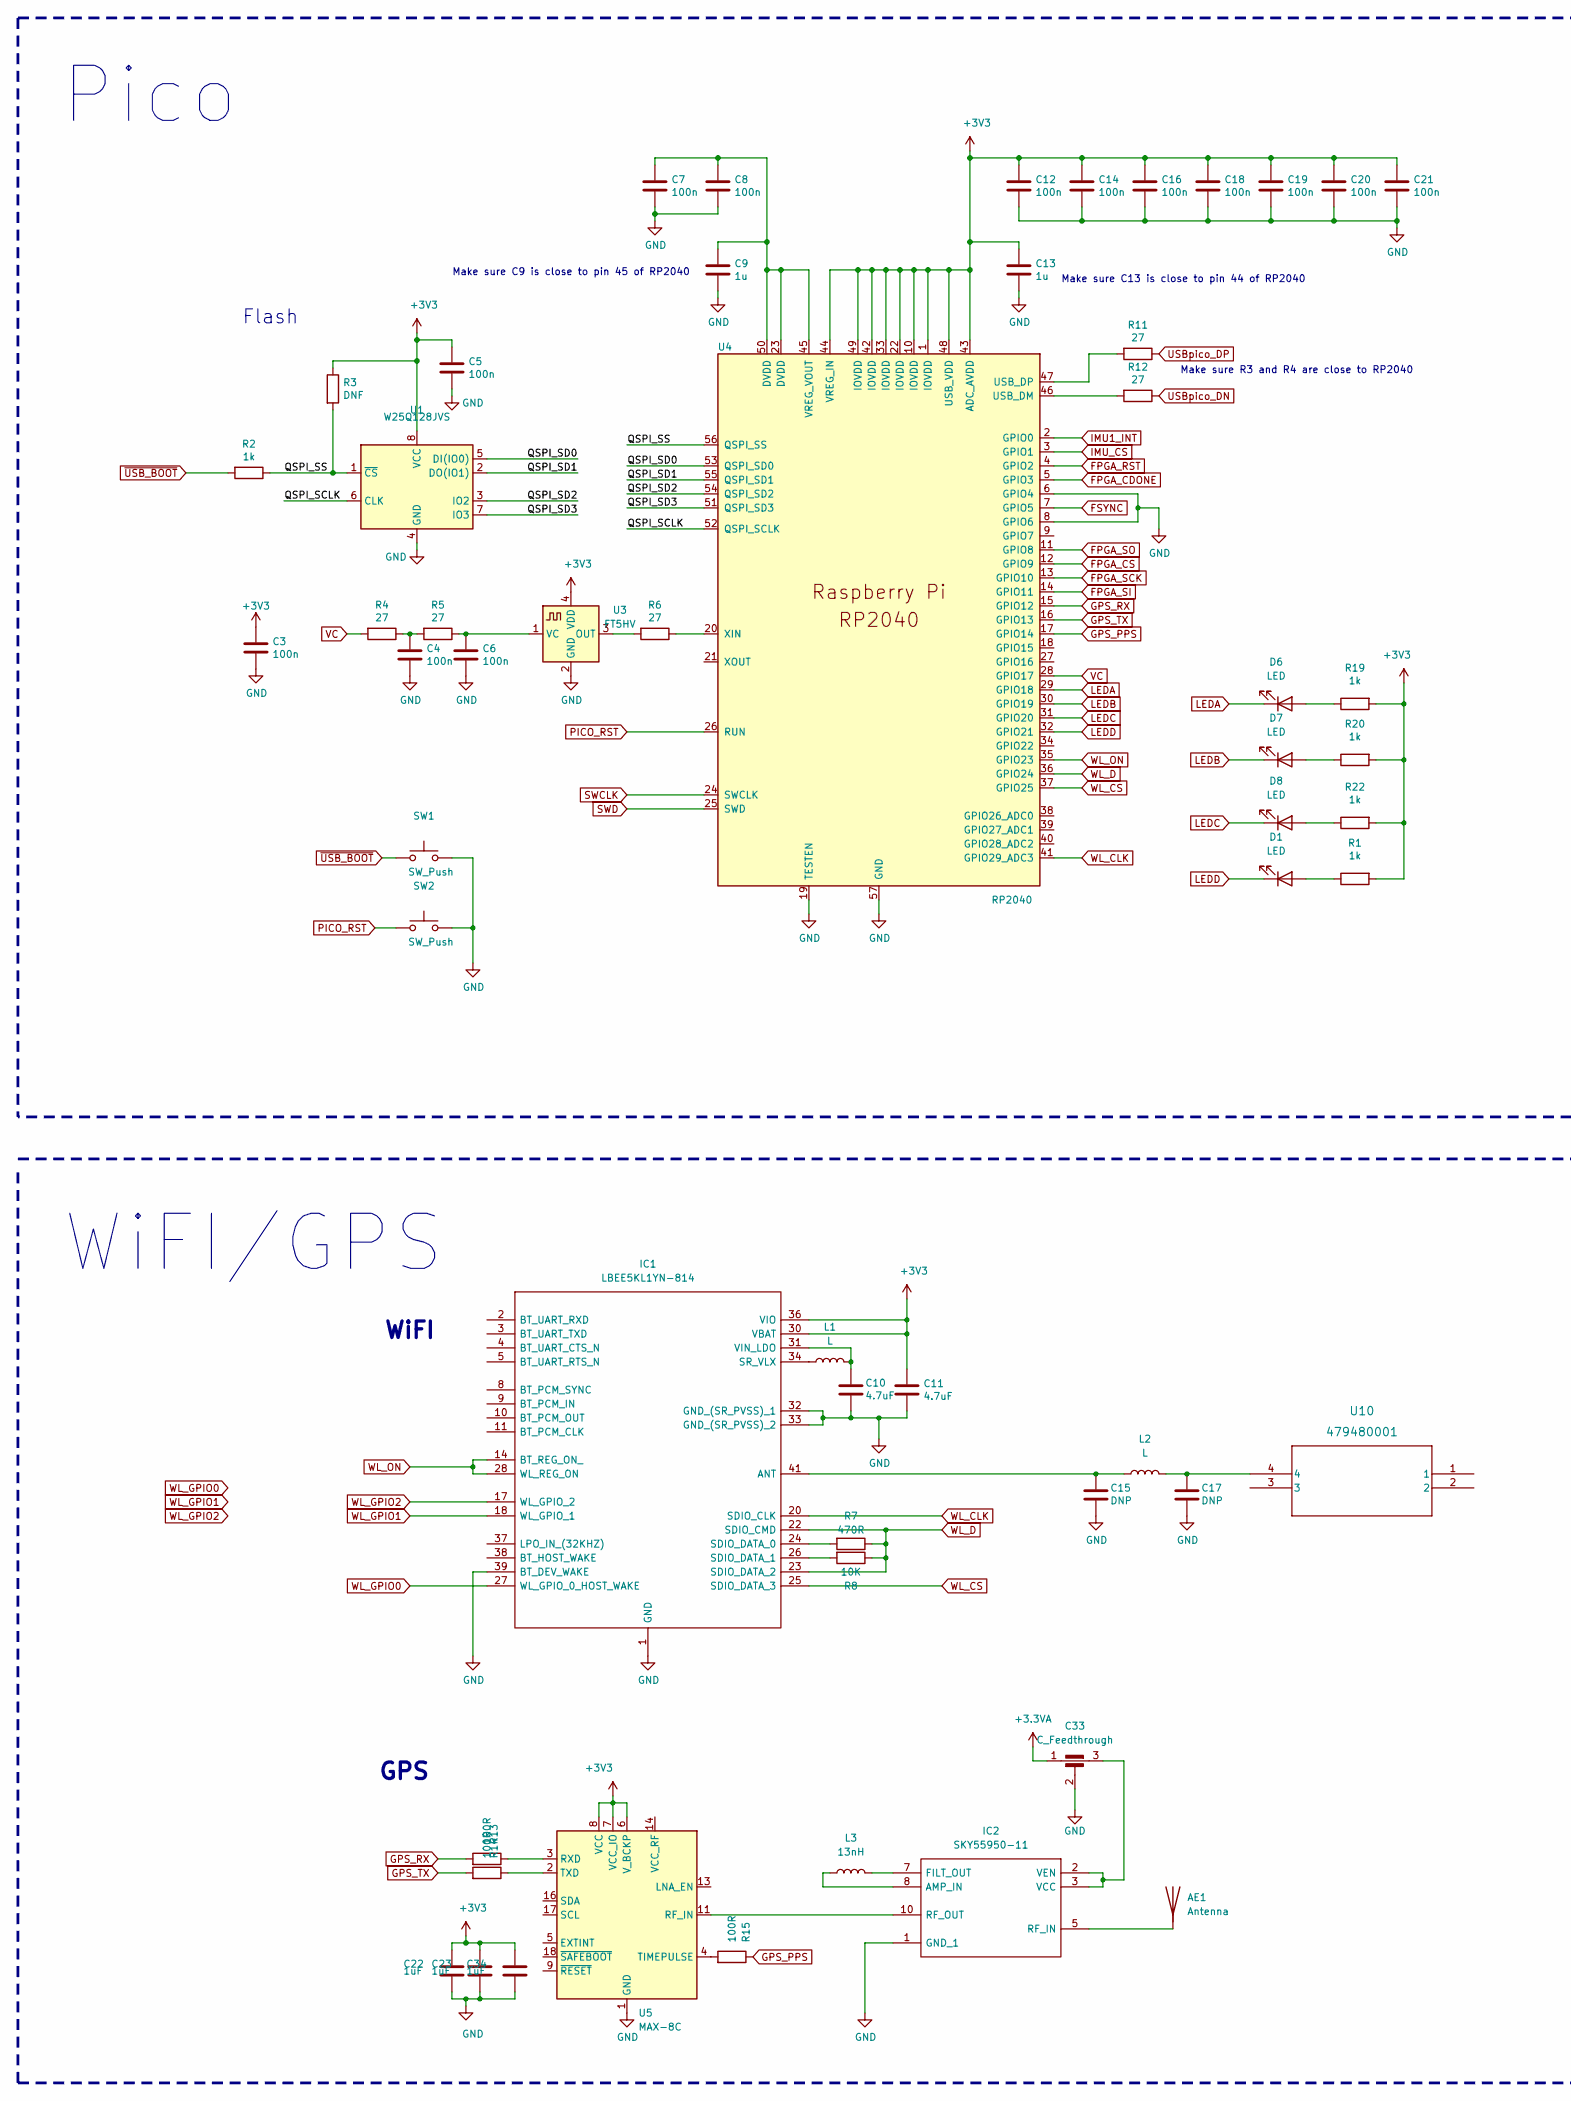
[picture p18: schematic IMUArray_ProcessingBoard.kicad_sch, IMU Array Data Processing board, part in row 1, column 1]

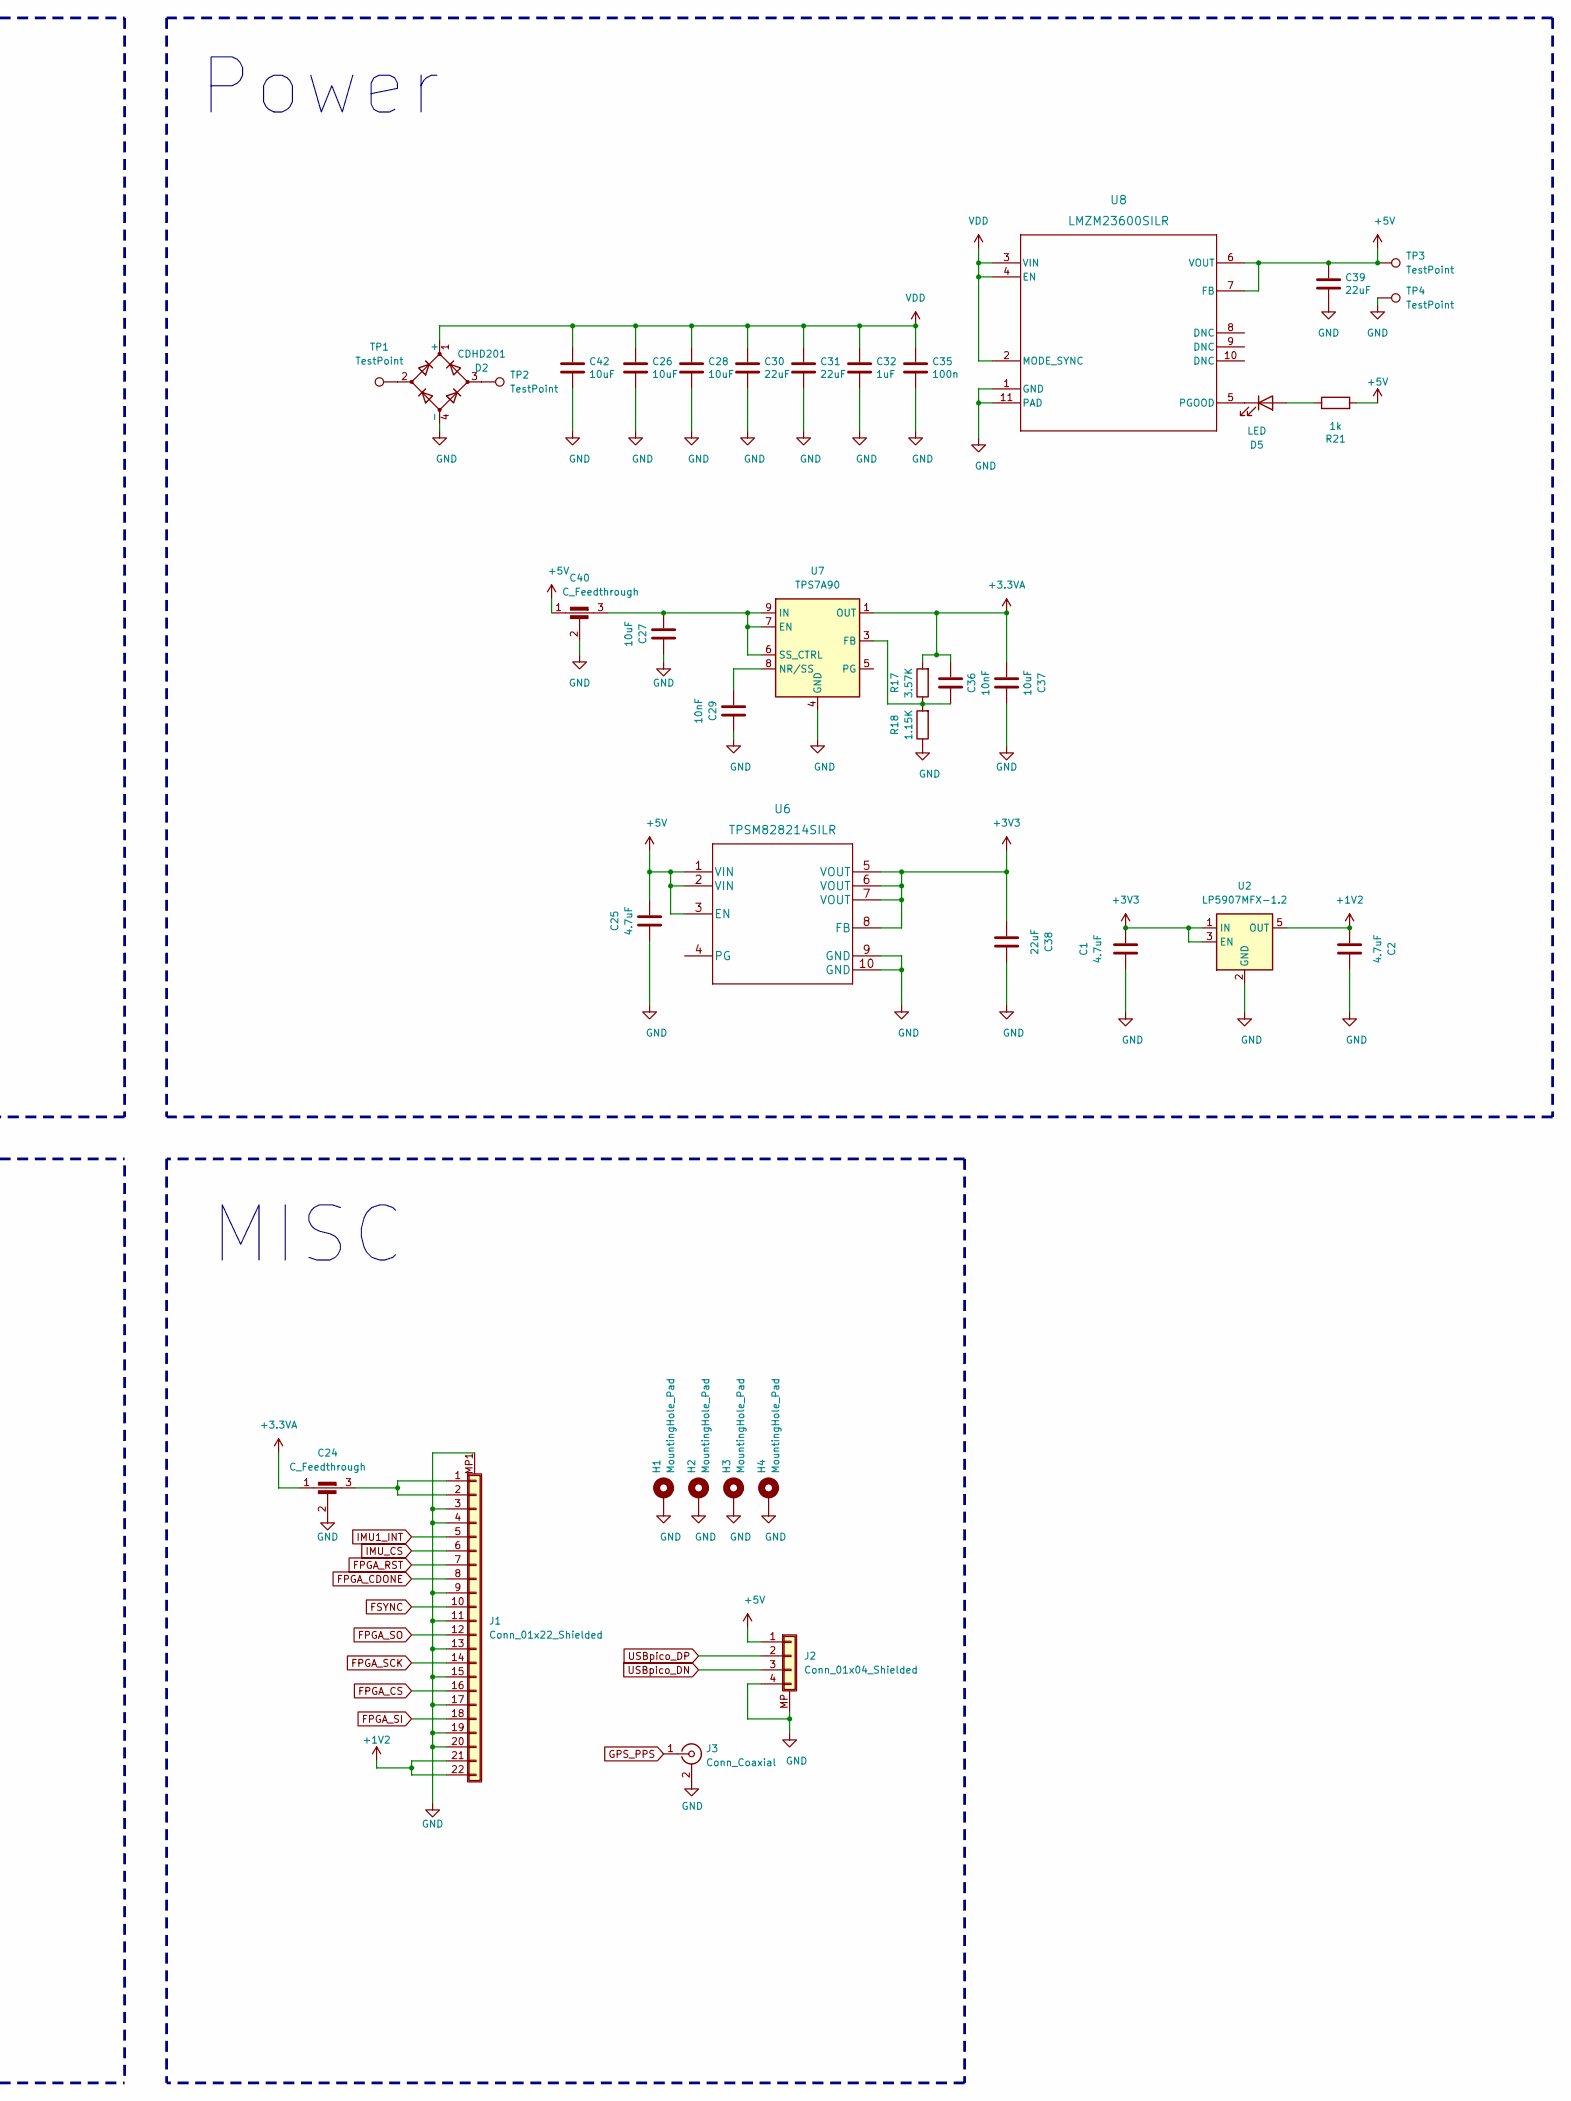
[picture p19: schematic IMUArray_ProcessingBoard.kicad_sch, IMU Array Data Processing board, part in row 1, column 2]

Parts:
AE1: Antenna; APAES1575R1040J34-T_ABR
C1, C2: 4.7uF; C_0603_1608Metric
C3, C4, C5, C6, C7, C8, C12, C14, C16, C18, C19, C20, C21: 100n; C_0402_1005Metric
C9, C13: 1u; C_0402_1005Metric
C10, C11: 4.7uF; C_0402_1005Metric
C15, C17: DNP; C_0402_1005Metric
C22, C23, C34: 1uF; C_0402_1005Metric
C24, C33, C40: C_Feedthrough; NFM18CC101R1C3D
C25: 4.7uF; C_0805_2012Metric
C26, C28, C42: 10uF; C_1206_3216Metric
C27, C37: 10uF; C_0603_1608Metric
C29, C36: 10nF; C_0402_1005Metric
C30, C31: 22uF; C_1206_3216Metric
C32: 1uF; C_0603_1608Metric
C35: 100n; C_0603_1608Metric
C38, C39: 22uF; C_0805_2012Metric
D1, D5, D6, D7, D8: LED; LED_0603_1608Metric
D2: CDHD201
H1, H2, H3, H4: MountingHole_Pad; MountingHole_3.2mm_M3_Pad
IC1: LBEE5KL1YN-814; LBEE5KL1YN814; Mouser Part Number 81-LBEE5KL1YN-814
IC2: SKY55950-11; SKY5595011; Mouser Part Number 873-SKY55950-11
J1: Conn_01x22_Shielded; Hirose_FH12-22S-0.5SH_1x22-1MP_P0.50mm_Horizontal
J2: Conn_01x04_Shielded; JST_SH_BM04B-SRSS-TB_1x04-1MP_P1.00mm_Vertical
J3: Conn_Coaxial; U.FL_Hirose_U.FL-R-SMT-1_Vertical
L1: L; L_0603_1608Metric
L2: L; L_0402_1005Metric
L3: 13nH; L_0402_1005Metric
R1, R2, R19, R20, R21, R22: 1k; C_0402_1005Metric
R3: DNF; C_0402_1005Metric
R4, R5, R6, R11, R12: 27; C_0402_1005Metric
R7: 470R; C_0402_1005Metric
R8: 10K; C_0402_1005Metric
R13, R14, R15: 100R; R_0402_1005Metric
R17: 3.57K; R_0402_1005Metric
R18: 1.15K; R_0402_1005Metric
SW1, SW2: SW_Push; SW_Push_SPST_NO_Alps_SKRK
TP1, TP2, TP3, TP4: TestPoint; TestPoint_Pad_D2.0mm
U1: W25Q128JVS; DFN-8-1EP_3x2mm_P0.5mm_EP1.36x1.46mm
U2: LP5907MFX-1.2; SOT-23-5
U3: FT5HV; Oscillator_SMD_SeikoEpson_SG8002CE-4Pin_3.2x2.5mm
U4: RP2040; RP2040-QFN-56
U5: MAX-8C; ublox_MAX
U6: TPSM828214SILR; TPSM82821SILR
U7: TPS7A90; Texas_S-PDSO-N10_EP1.2x2mm
U8: LMZM23600SILR; SIL0010A
U10: 479480001; ANT_47948-0001_MOL

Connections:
+1V2: C2.1, J1.21, J1.22, U2.5 (OUT)
+3.3VA: C24.1, C33.1, C36.2, C37.1, R17.2, U7.1 (OUT), U7.2 (OUT)
+3V3: C1.2, C3.1, C5.1, C11.1, C12.1, C13.1, C14.1, C16.1, C18.1, C19.1, C20.1, C21.1, C22.1, C23.1, C34.1, C38.1, IC1.30 (VBAT), IC1.36 (VIO), R1.2, R3.1, R19.2, R20.2, R22.2, U1.8 (VCC), U2.1 (IN), U2.3 (EN), U3.4 (VDD), U4.1 (IOVDD), U4.10 (IOVDD), U4.22 (IOVDD), U4.33 (IOVDD), U4.42 (IOVDD), U4.43 (ADC_AVDD), U4.44 (VREG_IN), U4.48 (USB_VDD), U4.49 (IOVDD), U5.6 (V_BCKP), U5.7 (VCC_IO), U5.8 (VCC), U6.5 (VOUT), U6.6 (VOUT), U6.7 (VOUT), U6.8 (FB)
+5V: C25.2, C39.1, C40.1, J2.1, R21.2, TP3.1, U6.1 (VIN), U6.2 (VIN), U6.3 (EN), U8.6 (VOUT), U8.7 (FB)
/QSPI_SCLK: U1.6 (CLK), U4.52 (QSPI_SCLK)
/QSPI_SD0: U1.5 (DI(IO0)), U4.53 (QSPI_SD0)
/QSPI_SD1: U1.2 (DO(IO1)), U4.55 (QSPI_SD1)
/QSPI_SD2: U1.3 (IO2), U4.54 (QSPI_SD2)
/QSPI_SD3: U1.7 (IO3), U4.51 (QSPI_SD3)
/QSPI_SS: R2.1, R3.2, U1.1 (~CS), U4.56 (QSPI_SS)
FPGA_CDONE: J1.8, U4.5 (GPIO3)
FPGA_CS: J1.16, U4.12 (GPIO9)
FPGA_RST: J1.7, U4.4 (GPIO2)
FPGA_SCK: J1.14, U4.13 (GPIO10)
FPGA_SI: J1.18, U4.14 (GPIO11)
FPGA_SO: J1.12, U4.11 (GPIO8)
FSYNC: J1.10, U4.7 (GPIO5)
GND: C1.1, C2.2, C3.2, C4.2, C5.2, C6.2, C7.2, C8.2, C9.2, C10.2, C11.2, C12.2, C13.2, C14.2, C15.2, C16.2, C17.2, C18.2, C19.2, C20.2, C21.2, C22.2, C23.2, C24.2, C25.1, C26.2, C27.2, C28.2, C29.2, C30.2, C31.2, C32.2, C33.2, C34.2, C35.2, C37.2, C38.2, C39.2, C40.2, C42.2, D2.4 (-), H1.1, H2.1, H3.1, H4.1, IC1.1 (GND), IC1.12 (GND_2), IC1.19 (GND_3), IC1.21 (GND_4), IC1.29 (GND_5), IC1.32 (GND_(SR_PVSS)_1), IC1.33 (GND_(SR_PVSS)_2), IC1.35 (GND_6), IC1.39 (BT_DEV_WAKE), IC1.40 (GND_7), IC1.42 (GND_8), IC1.43 (GND_9), IC1.44 (GND_10), IC1.45 (GND_11), IC1.46 (GND_12), IC2.1 (GND_1), IC2.4 (GND_2), IC2.6 (GND_3), IC2.9 (GND_4), IC2.11 (GND_5), J1.3, J1.4, J1.9, J1.11, J1.13, J1.15, J1.17, J1.19, J1.20, J1.MP1 (Shield), J1.MP2 (Shield), J2.4, J2.MP (Shield), J3.2 (Ext), R18.1, SW1.2, SW2.2, TP4.1, U1.4 (GND), U2.2 (GND), U3.2 (GND), U4.6 (GPIO4), U4.8 (GPIO6), U4.19 (TESTEN), U4.57 (GND), U5.1 (GND), U5.10 (GND), U5.12 (GND), U6.9 (GND), U6.10 (GND), U7.4 (GND), U7.11 (GND), U8.1 (GND), U8.11 (PAD)
GPS_PPS: J3.1 (In), R15.1, U4.17 (GPIO14)
GPS_RX: R13.2, U4.15 (GPIO12)
GPS_TX: R14.2, U4.16 (GPIO13)
IMU1_INT: J1.5, U4.2 (GPIO0)
IMU_CS: J1.6, U4.3 (GPIO1)
LEDA: D6.1 (K), U4.29 (GPIO18)
LEDB: D7.1 (K), U4.30 (GPIO19)
LEDC: D8.1 (K), U4.31 (GPIO20)
LEDD: D1.1 (K), U4.32 (GPIO21)
unnamed: AE1.1 (A), IC2.5 (RF_IN)
unnamed: C4.1, R4.1, R5.2
unnamed: C17.1, L2.2, U10.4
unnamed: D1.2 (A), R1.1
unnamed: D2.2, TP1.1
unnamed: D2.3, TP2.1
unnamed: D5.2 (A), R21.1
unnamed: D5.1 (K), U8.5 (PGOOD)
unnamed: D6.2 (A), R19.1
unnamed: D7.2 (A), R20.1
unnamed: D8.2 (A), R22.1
unnamed: C15.1, IC1.41 (ANT), L2.1
unnamed: IC1.24 (SDIO_DATA_0), R7.2
unnamed: IC1.26 (SDIO_DATA_1), R8.2
unnamed: IC1.34 (SR_VLX), L1.1
unnamed: C10.1, IC1.31 (VIN_LDO), L1.2
unnamed: IC2.8 (AMP_IN), L3.1
unnamed: IC2.7 (FILT_OUT), L3.2
unnamed: IC2.10 (RF_OUT), U5.11 (RF_IN)
unnamed: C33.3, IC2.2 (VEN), IC2.3 (VCC)
unnamed: C24.3, J1.1, J1.2
unnamed: R6.2, U3.3 (OUT)
unnamed: C6.1, R5.1, U3.1 (VC)
unnamed: R12.2, U4.46 (USB_DM)
unnamed: R11.2, U4.47 (USB_DP)
unnamed: C7.1, C8.1, C9.1, U4.23 (DVDD), U4.45 (VREG_VOUT), U4.50 (DVDD)
unnamed: R6.1, U4.20 (XIN)
unnamed: R13.1, U5.3 (RXD)
unnamed: R15.2, U5.4 (TIMEPULSE)
unnamed: R14.1, U5.2 (TXD)
unnamed: C27.1, C40.3, U7.6 (SS_CTRL), U7.7 (EN), U7.9 (IN), U7.10 (IN)
unnamed: C36.1, R17.1, R18.2, U7.3 (FB)
unnamed: C29.1, U7.8 (NR/SS)
PICO_RST: SW2.1, U4.26 (RUN)
SWCLK: U4.24 (SWCLK)
SWD: U4.25 (SWD)
USBpico_DN: J2.3, R12.1
USBpico_DP: J2.2, R11.1
VC: R4.2, U4.28 (GPIO17)
VDD: C26.1, C28.1, C30.1, C31.1, C32.1, C35.1, C42.1, D2.1 (+), U8.2 (MODE_SYNC), U8.3 (VIN), U8.4 (EN)
WL_CLK: IC1.20 (SDIO_CLK), U4.41 (GPIO29_ADC3)
WL_CS: IC1.25 (SDIO_DATA_3), U4.37 (GPIO25)
WL_D: IC1.22 (SDIO_CMD), IC1.23 (SDIO_DATA_2), R7.1, R8.1, U4.36 (GPIO24)
WL_GPIO0: IC1.27 (WL_GPIO_0_HOST_WAKE)
WL_GPIO1: IC1.18 (WL_GPIO_1)
WL_GPIO2: IC1.17 (WL_GPIO_2)
WL_ON: IC1.14 (BT_REG_ON_), IC1.28 (WL_REG_ON), U4.35 (GPIO23)
~USB_BOOT: R2.2, SW1.1

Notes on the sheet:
WiFI
Make sure R3 and R4 are close to RP2040
GPS
Make sure C9 is close to pin 45 of RP2040
Power
MISC
WiFI/GPS
Make sure C13 is close to pin 44 of RP2040
Pico
Flash

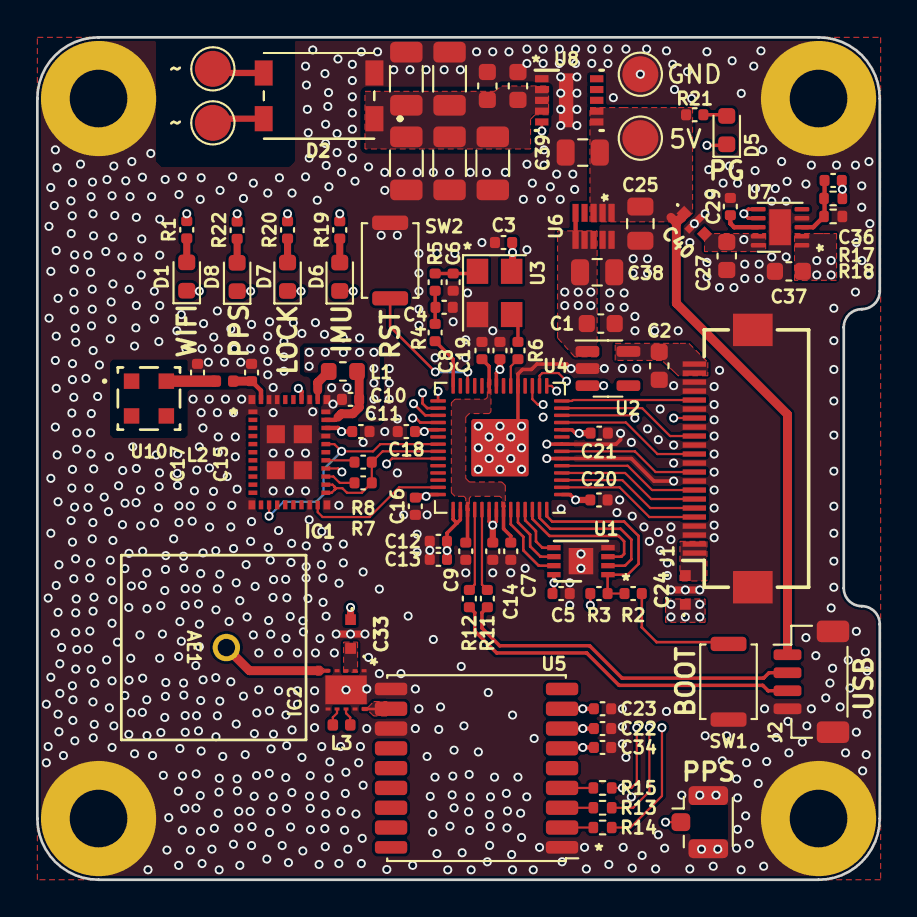
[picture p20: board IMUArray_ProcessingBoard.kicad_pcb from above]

Board: 4 copper layers, 46.8 x 46.8 mm, 94 parts (0 on the bottom side), 70 nets.

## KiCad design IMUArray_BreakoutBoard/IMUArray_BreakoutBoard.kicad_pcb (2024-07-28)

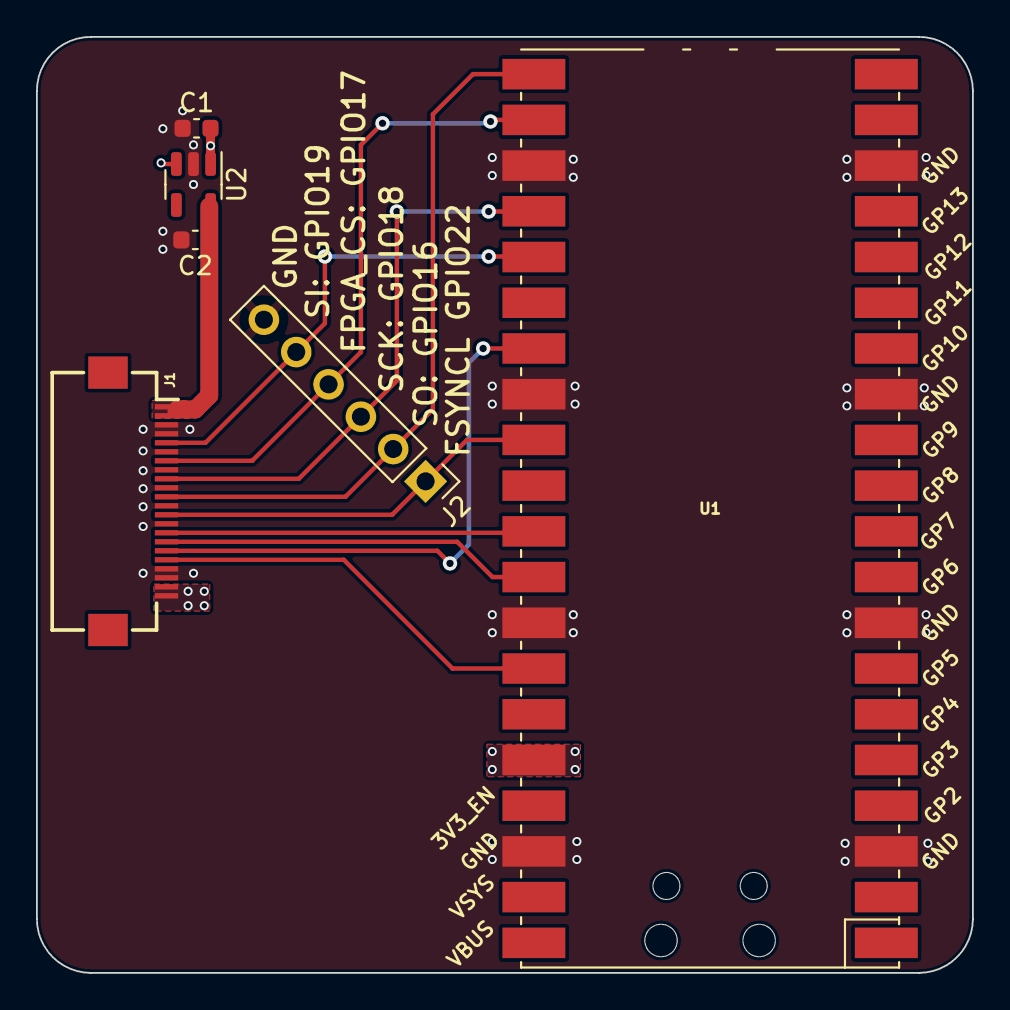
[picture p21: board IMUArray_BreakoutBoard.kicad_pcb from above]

Board: 4 copper layers, 52.0 x 52.0 mm, 6 parts (0 on the bottom side), 12 nets.

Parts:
C1, C2: 4.7uF; C_0603_1608Metric
J1: Conn_01x22_Shielded; Hirose_FH12-22S-0.5SH_1x22-1MP_P0.50mm_Horizontal
J2: Conn_01x06; PinHeader_1x06_P2.54mm_Vertical
U1: Pico; RPi_Pico_SMD_TH
U2: LP5907MFX-1.2; SOT-23-5

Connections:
+1V2: C2.1, J1.1, J1.2, U2.5 (OUT)
+3V3: C1.2, J1.21, J1.22, U1.36 (3V3), U2.1 (IN), U2.3 (EN)
FPGA_CDONE: J1.15, U1.31 (GPIO26_ADC0)
FPGA_CS: J1.7, J2.4, U1.22 (GPIO17)
FPGA_RST: J1.16, U1.32 (GPIO27_ADC1)
FPGA_SCK: J1.9, J2.3, U1.24 (GPIO18)
FPGA_SI: J1.5, J2.5, U1.25 (GPIO19)
FPGA_SO: J1.11, J2.2, U1.21 (GPIO16)
FSYNC: J1.13, J2.1, U1.29 (GPIO22)
GND: C1.1, C2.2, J1.3, J1.4, J1.6, J1.8, J1.10, J1.12, J1.14, J1.19, J1.20, J2.6, U1.3 (GND), U1.8 (GND), U1.13 (GND), U1.18 (GND), U1.23 (GND), U1.28 (GND), U1.33 (AGND), U1.38 (GND), U2.2 (GND)
IMU1_INT: J1.18, U1.34 (GPIO28_ADC2)
IMU_CS: J1.17, U1.27 (GPIO21)

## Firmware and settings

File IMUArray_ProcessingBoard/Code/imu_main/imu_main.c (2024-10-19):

#include <stdio.h>
#include <stdlib.h>
#include "pico/stdlib.h"

#include "hardware/spi.h"
#include "hardware/pwm.h"
#include "hardware/pio.h"
#include "hardware/uart.h"
#include "hardware/clocks.h"
#include "hardware/irq.h"
#include "hardware/gpio.h"

#include "pico/cyw43_arch.h"
#include "pico/multicore.h"
#include "pico/time.h"
#include "pico/unique_id.h"

#include "lwip/pbuf.h"
#include "lwip/tcp.h"

// Include custom headers
#include "hardware_pins.h"
#include "imu_fifo.h"
#include "imu_processing.h"
#include "ntp_sync.h"
#include "tcp_server.h"
#include "gpsdo.h"
#include "inputCapture.pio.h" // For the PIO program
#include "tinygps.h"          // For GPS handling
#include "config.h"


// Global Variables
imu_fifo_t imu_fifo;
TCP_SERVER_T *tcp_state;
NTP_T ntp_state;

// Forward Declarations
void core1_entry();
void imu_gpio_callback(uint gpio, uint32_t events);

// Main Function
int main() {
    // Set system clock frequency
    set_sys_clock_khz(SYS_CLOCK_KHZ, true);

    // Initialize standard I/O
    stdio_init_all();

    printf("[INIT] Starting up...\n");

    // Initialize IMU FIFO
    imu_fifo_init(&imu_fifo);

    // Initialize GPIO pins
    gpio_init(FPGA_RST);
    gpio_set_dir(FPGA_RST, GPIO_OUT);
    gpio_put(FPGA_RST, 1);

    gpio_init(FPGA_CS);
    gpio_set_dir(FPGA_CS, GPIO_OUT);
    gpio_put(FPGA_CS, 1);

    gpio_init(IMU_CS);
    gpio_set_dir(IMU_CS, GPIO_OUT);
    gpio_put(IMU_CS, 1);

    gpio_init(IMU_INT);
    gpio_set_dir(IMU_INT, GPIO_IN);

    gpio_init(LED_IMU);
    gpio_set_dir(LED_IMU, GPIO_OUT);
    gpio_init(LED_LOCK);
    gpio_set_dir(LED_LOCK, GPIO_OUT);
    gpio_init(LED_PPS);
    gpio_set_dir(LED_PPS, GPIO_OUT);
    gpio_init(LED_WIFI);
    gpio_set_dir(LED_WIFI, GPIO_OUT);

    gpio_put(LED_IMU, 1);
    gpio_put(LED_LOCK, 1);
    gpio_put(LED_PPS, 1);
    gpio_put(LED_WIFI, 1);

    // Initialize SPI for FPGA and IMU
    spi_init(spi1, 20 * 1000 * 1000);

    gpio_set_function(FPGA_RX, GPIO_FUNC_SPI);
    gpio_set_function(FPGA_SCK, GPIO_FUNC_SPI);
    gpio_set_function(FPGA_TX, GPIO_FUNC_SPI);

    // Initialize UART for GPS
    uart_init(uart0, 115200);
    gpio_set_function(GPS_RX, GPIO_FUNC_UART);
    gpio_set_function(GPS_TX, GPIO_FUNC_UART);

    // Initialize PWM for VCXO control
    gpio_set_function(VC, GPIO_FUNC_PWM);
    uint slice_num = pwm_gpio_to_slice_num(VC);

    pwm_config config = pwm_get_default_config();
    pwm_config_set_wrap(&config, 8192);
    pwm_init(slice_num, &config, true);
    pwm_set_gpio_level(VC, 3846); // Initial PWM value

    // Initialize PIO for PPS input capture
    PIO pio_inputCapture = pio0;
    uint sm = 0;
    uint offset = pio_add_program(pio_inputCapture, &capture_program);
    gpsdo_init(pio_inputCapture, sm, offset, GPS_PPS);
    pio_sm_set_enabled(pio_inputCapture, sm, true);

    // Initialize FSYNC signal
    printf("[INIT] Setting up FSYNC\n");
    gpio_set_function(FSYNC, GPIO_FUNC_PWM);
    uint fsync_slice_num = pwm_gpio_to_slice_num(FSYNC);

    pwm_config fsync_config = pwm_get_default_config();
    pwm_config_set_wrap(&fsync_config, 29);
    pwm_init(fsync_slice_num, &fsync_config, true);
    pwm_set_clkdiv(fsync_slice_num, 250);
    pwm_set_gpio_level(FSYNC, 15);

    // Initialize Wi-Fi
    if (cyw43_arch_init()) {
        printf("[INIT] Failed to initialize Wi-Fi\n");
        return 1;
    }
    cyw43_arch_enable_sta_mode();

    printf("[INIT] Connecting to Wi-Fi...\n");
    while (true) {
        if (cyw43_arch_wifi_connect_timeout_ms(WIFI_SSID, WIFI_PASSWORD, CYW43_AUTH_WPA2_AES_PSK, 10000)) {
            printf("[INIT] Failed to connect to Wi-Fi.\n");
        } else {
            printf("[INIT] Connected to Wi-Fi.\n");
            gpio_put(LED_WIFI, 0);
            break;
        }
    }

    // Initialize TCP server
    tcp_state = tcp_server_init();
    if (!tcp_state) {
        printf("[INIT] Failed to initialize TCP server\n");
        return 1;
    }
    if (!tcp_server_open(tcp_state)) {
        printf("[INIT] Failed to open TCP server\n");
        return 1;
    }

    // Initialize NTP synchronization
    ntp_init(&ntp_state);
    ntp_sync_time(&ntp_state);

    // Initialize FPGA
    initFPGA();

    // Launch core 1 for IMU and GPS handling
    printf("[INIT] Launching core 1\n");
    multicore_launch_core1(core1_entry);


    static uint64_t last_ntp_sync_us = 0;

    // Main Loop
    while (1) {
        // Poll the Wi-Fi driver
        cyw43_arch_poll();

        // Schedule NTP synchronization every hour
        uint64_t now_us = time_us_64();
        if ((now_us - last_ntp_sync_us) > 3600ULL * 1000000ULL) { // Every hour
            ntp_sync_time(&ntp_state);
            last_ntp_sync_us = now_us;
        }

        // Check if a client is connected
        if (tcp_state->client_pcb && tcp_state->client_connected) {
            imu_data_t imu_data;
            // Pop data from the IMU FIFO and send over TCP
            while (imu_fifo_pop(&imu_fifo, &imu_data)) {
                err_t err = tcp_server_send_data(tcp_state, tcp_state->client_pcb, (uint8_t*)&imu_data, sizeof(imu_data_t));
                if (err != ERR_OK) {
                    // Handle error
                    printf("[TCP] Error sending data: %d\n", err);
                    break;
                }
            }
        }
    }

    // Cleanup (if the main loop ever exits)
    tcp_server_deinit(tcp_state);
    cyw43_arch_deinit();
    return 0;
}

// Core 1 entry function
void core1_entry() {
    // Initialize IMU
    init_imu(IMU_200Hz);

    // Set up IMU interrupt handler
    gpio_set_irq_enabled_with_callback(IMU_INT, GPIO_IRQ_EDGE_FALL, true, &imu_gpio_callback);

    // Start IMU measurements
    start_measure();

    // Core 1 main loop
    while (1) {
        // Handle GPS data
        if (uart_is_readable(uart0)) {
            uint8_t ch = uart_getc(uart0);
            if (gps_encode(ch)) {
                int year;
                uint8_t month, day, hour, minute, second;
                gps_crack_datetime(&year, &month, &day, &hour, &minute, &second, NULL, NULL);

                // Convert GPS time to UNIX time
                struct tm t = {
                    .tm_year = year - 1900,
                    .tm_mon  = month - 1,
                    .tm_mday = day,
                    .tm_hour = hour,
                    .tm_min  = minute,
                    .tm_sec  = second
                };
                time_t gps_unixtime = mktime(&t);

                // Store the GPS time to be used at the next PPS interrupt
                gps_last_received_unixtime = gps_unixtime;
                gps_time_valid = true;

                // Optional: Print the time for debugging
                char timeStr[100] = {0};
                strftime(timeStr, sizeof(timeStr), "%Y/%m/%d %H:%M:%S", &t);

                printf("[GPS] GPS Time received: %s, GPS sat: %d\n", timeStr, gps_satellites());

                if (gps_satellites() > 4) {
                    gpio_put(LED_LOCK, 0);
                } else {
                    gpio_put(LED_LOCK, 1);
                }
            }
        }
    }
}

// IMU INT interrupt callback
void imu_gpio_callback(uint gpio, uint32_t events) {
    readIMU();  // Read IMU data and store in FIFO
}

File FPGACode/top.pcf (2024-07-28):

# ##############################################################################

# iCEcube PCF

# Version:            2017.08.27940

# File Generated:     Mar 31 2019 12:09:07

# Family & Device:    iCE5LP4K

# Package:            SG48

# ##############################################################################

###IOSet List

set_io LEDR 41
set_io LEDG 40
set_io LEDB 39
set_io MOSI 17
set_io CS 16
set_io SCK 15
set_io MISO 14
set_io IMU_MISO28 36 -pullup yes
set_io IMU_MISO24 37 -pullup yes
set_io IMU_MISO19 38 -pullup yes
set_io IMU_MISO31 28 -pullup yes
set_io IMU_MISO32 26 -pullup yes
set_io IMU_MISO23 42 -pullup yes
set_io IMU_MISO29 35 -pullup yes
set_io IMU_MISO27 27 -pullup yes
set_io IMU_MISO4 25 -pullup yes
set_io IMU_MISO5 23 -pullup yes
set_io IMU_MISO18 43 -pullup yes
set_io IMU_MISO26 31 -pullup yes
set_io IMU_MISO25 34 -pullup yes
set_io IMU_MISO30 32 -pullup yes
set_io IMU_MISO13 10 -pullup yes
set_io IMU_MISO1 21 -pullup yes
set_io IMU_MISO12 11 -pullup yes
set_io IMU_MISO7 18 -pullup yes
set_io IMU_MISO2 19 -pullup yes
set_io IMU_MISO8 12 -pullup yes
set_io IMU_MISO3 13 -pullup yes
set_io IMU_MISO14 6 -pullup yes
set_io IMU_MISO9 9 -pullup yes
set_io IMU_MISO6 20 -pullup yes
set_io IMU_MISO11 2 -pullup yes
set_io IMU_MISO21 46 -pullup yes
set_io IMU_MISO22 44 -pullup yes
set_io IMU_MISO16 48 -pullup yes
set_io IMU_MISO20 47 -pullup yes
set_io IMU_MISO17 45 -pullup yes
set_io IMU_MISO15 3 -pullup yes
set_io IMU_MISO10 4 -pullup yes

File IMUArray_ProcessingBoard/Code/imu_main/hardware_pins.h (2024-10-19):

#ifndef HARDWARE_PINS_H
#define HARDWARE_PINS_H

// GPIO Pin Definitions
#define IMU_INT 0
#define IMU_CS 1
#define FPGA_RST 2
#define FPGA_CDONE 3
#define FSYNC 5
#define FPGA_RX 8
#define FPGA_CS 9
#define FPGA_SCK 10
#define FPGA_TX 11
#define GPS_RX 12
#define GPS_TX 13
#define GPS_PPS 14
#define VC 17
#define LED_IMU 18
#define LED_LOCK 19
#define LED_PPS 20
#define LED_WIFI 21

#endif // HARDWARE_PINS_H

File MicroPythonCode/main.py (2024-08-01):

import time
from machine import Pin, SPI, PWM
import oakdevtech_icepython
from ICM42688P import IMU

machine.freq(250000000)

IMU_CS = Pin(21, Pin.OUT) 
IMU_CS.value(1) 

FSYNC = PWM(Pin(22), freq=32000, duty_u16=32768)
spi = SPI(0, 5_000_000, sck=Pin(18), mosi=Pin(19), miso=Pin(16), polarity=1, phase=1)

iceprog = oakdevtech_icepython.Oakdevtech_icepython(
    spi, 17 , 27 , "main_bitmap.bin"
)
 
iceprog.program_fpga() 
spi.deinit()

#If the reading is triggered by interrupt and not busy loop, Thonny won't have the time to stop the code
#So the delay here is just in case you want to stop it.
time.sleep(5)

spi = SPI(0, 10_000_000, sck=Pin(18), mosi=Pin(19), miso=Pin(16), polarity=0, phase=0)

IMU = IMU(spi,IMU_CS,iceprog._chip_sel,rate=2) #100Hz


def callback(p):
    IMU.readIMU_CSV()
    #IMU.readIMU_average()

IMU_DRDY = Pin(28, Pin.IN)
IMU_DRDY.irq(trigger=Pin.IRQ_FALLING, handler=callback)

while True:
    #IMU.readIMU_CSV()
    time.sleep(1)

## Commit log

2024-08-01 Update FPGA SPI code + testbench code
2024-10-19 Adding IMU processing board v1.0 and its code
    [Body.stl, IMUArray_ProcessingBoard.kicad_pcb, IMUArray_ProcessingBoard.kicad_sch]

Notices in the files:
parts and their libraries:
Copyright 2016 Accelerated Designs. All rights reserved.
